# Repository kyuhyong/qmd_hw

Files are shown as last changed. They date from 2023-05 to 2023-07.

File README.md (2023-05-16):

# Q_Motor_Driver_hw

A stackable BLDC motor controller board based and compatible with Odrive project (https://github.com/madcowswe/ODriveHardware).

Part of this project is based from azmat's single channel BLDC controller board (https://github.com/azmat-bilal/bldc_motor_controller_pcb.git)

## Introduction

This project includes 3 PCB boards as Main Board(MB), M0 Board(M0B) and M1 Board(M1B). 

- MB : Main controller, USB, CAN interface

- M0B : Gate driver for M0, 5V power supply for MB
- M1B : Gate driver for M1

MB is in between M0B and M1B which are connected by 2mm pitch socket and header. 

If only 1 axis needed the M1B can be removed. 

If more power is needed, simply redesign M0B or M1B with higher power FET's and put together with MB.

## Odrive compatibility

This project is supposed to be compatible with odrive v3.6-56V.

<div align="center">
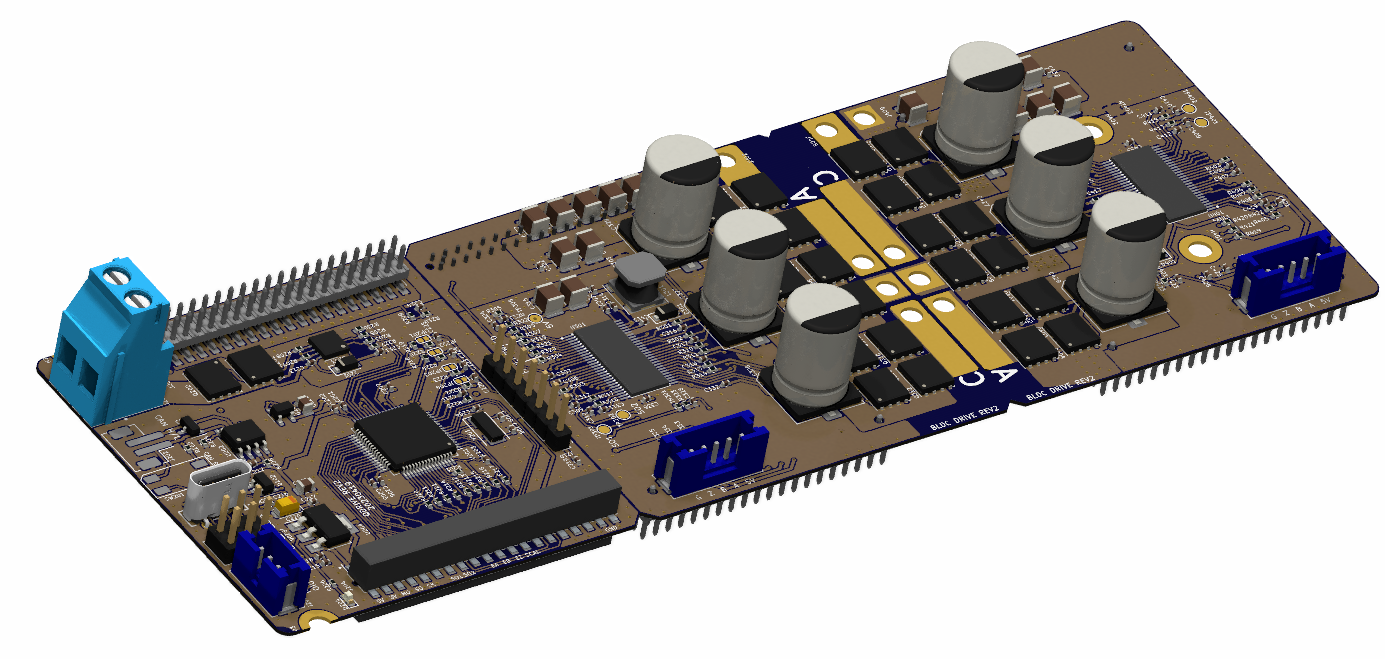
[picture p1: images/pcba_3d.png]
  
</div>

## Announcement

This project is still in development and need modification to be working as expected.

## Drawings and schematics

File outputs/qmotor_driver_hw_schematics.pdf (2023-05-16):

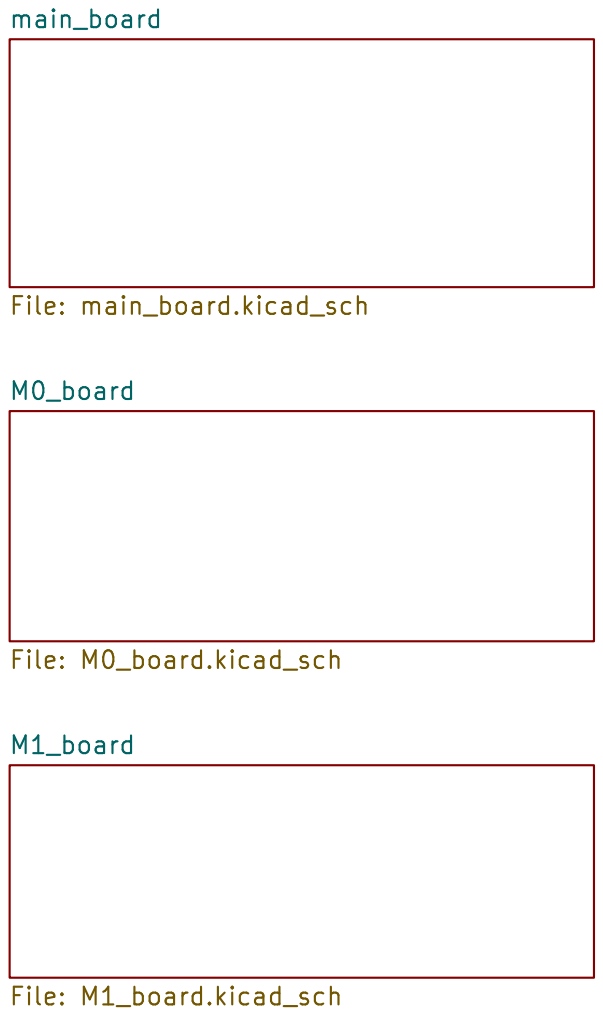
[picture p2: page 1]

Id: 1/4 Title: Q BLDC Motor Driver MB

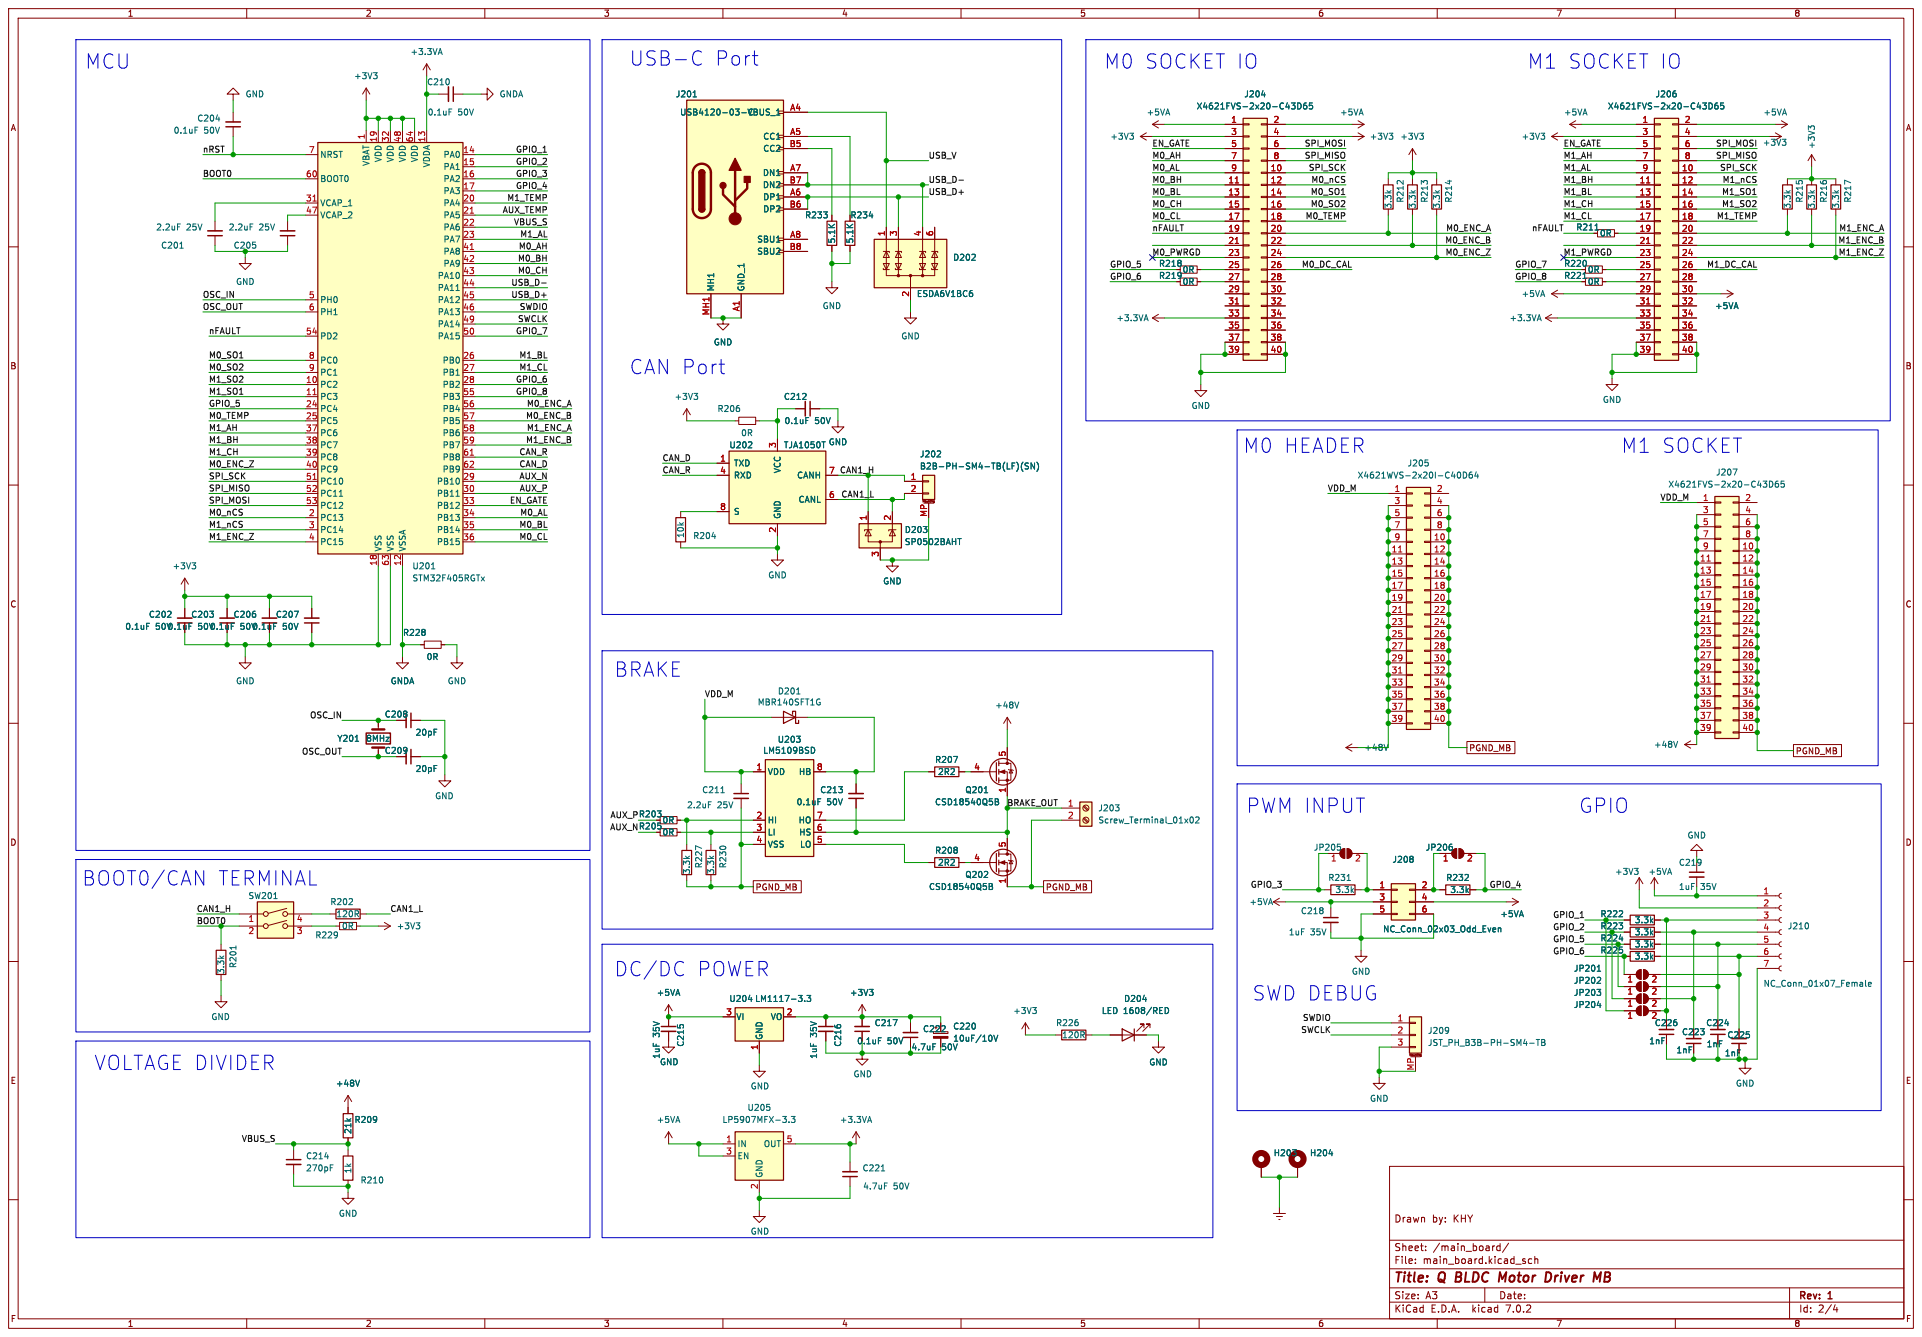
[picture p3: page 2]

1 PC2 10 PC3 11 VSSA 12 VDDA 13 PA0 14 PA1 15 PA2 16 PA3 17 VSS 18 VDD 19 PC13 2 PA4 20 PA5 21 PA6 22 PA7 23 PC4 24 PC5 25 PB0 26 PB1 27 PB2 28 PB10 29 PC14 3 PB11 30 VCAP_1 31 VDD 32 PB12 33 PB13 34 PB14 35 PB15 36 PC6 37 PC7 38 PC8 39 PC15 4 PC9 40 PA8 41 PA9 42 PA10 43 PA11 44 PA12 45 PA13 46 VCAP_2 47 VDD 48 PA14 49 PH0 5 PA15 50 PC10 51 PC11 52 PC12 53 PD2 54 PB3 55 PB4 56 PB5 57 PB6 58 PB7 59 PH1 6 BOOT0 60 PB8 61 PB9 62 VSS 63 VDD 64 NRST 7 PC0 8 PC1 9 U201 STM32F405RGTx +3V3 R228

J202 B2B-PH-SM4-TB(LF)(SN) GND

Id: 2/4 Title: Q BLDC Motor Driver MB

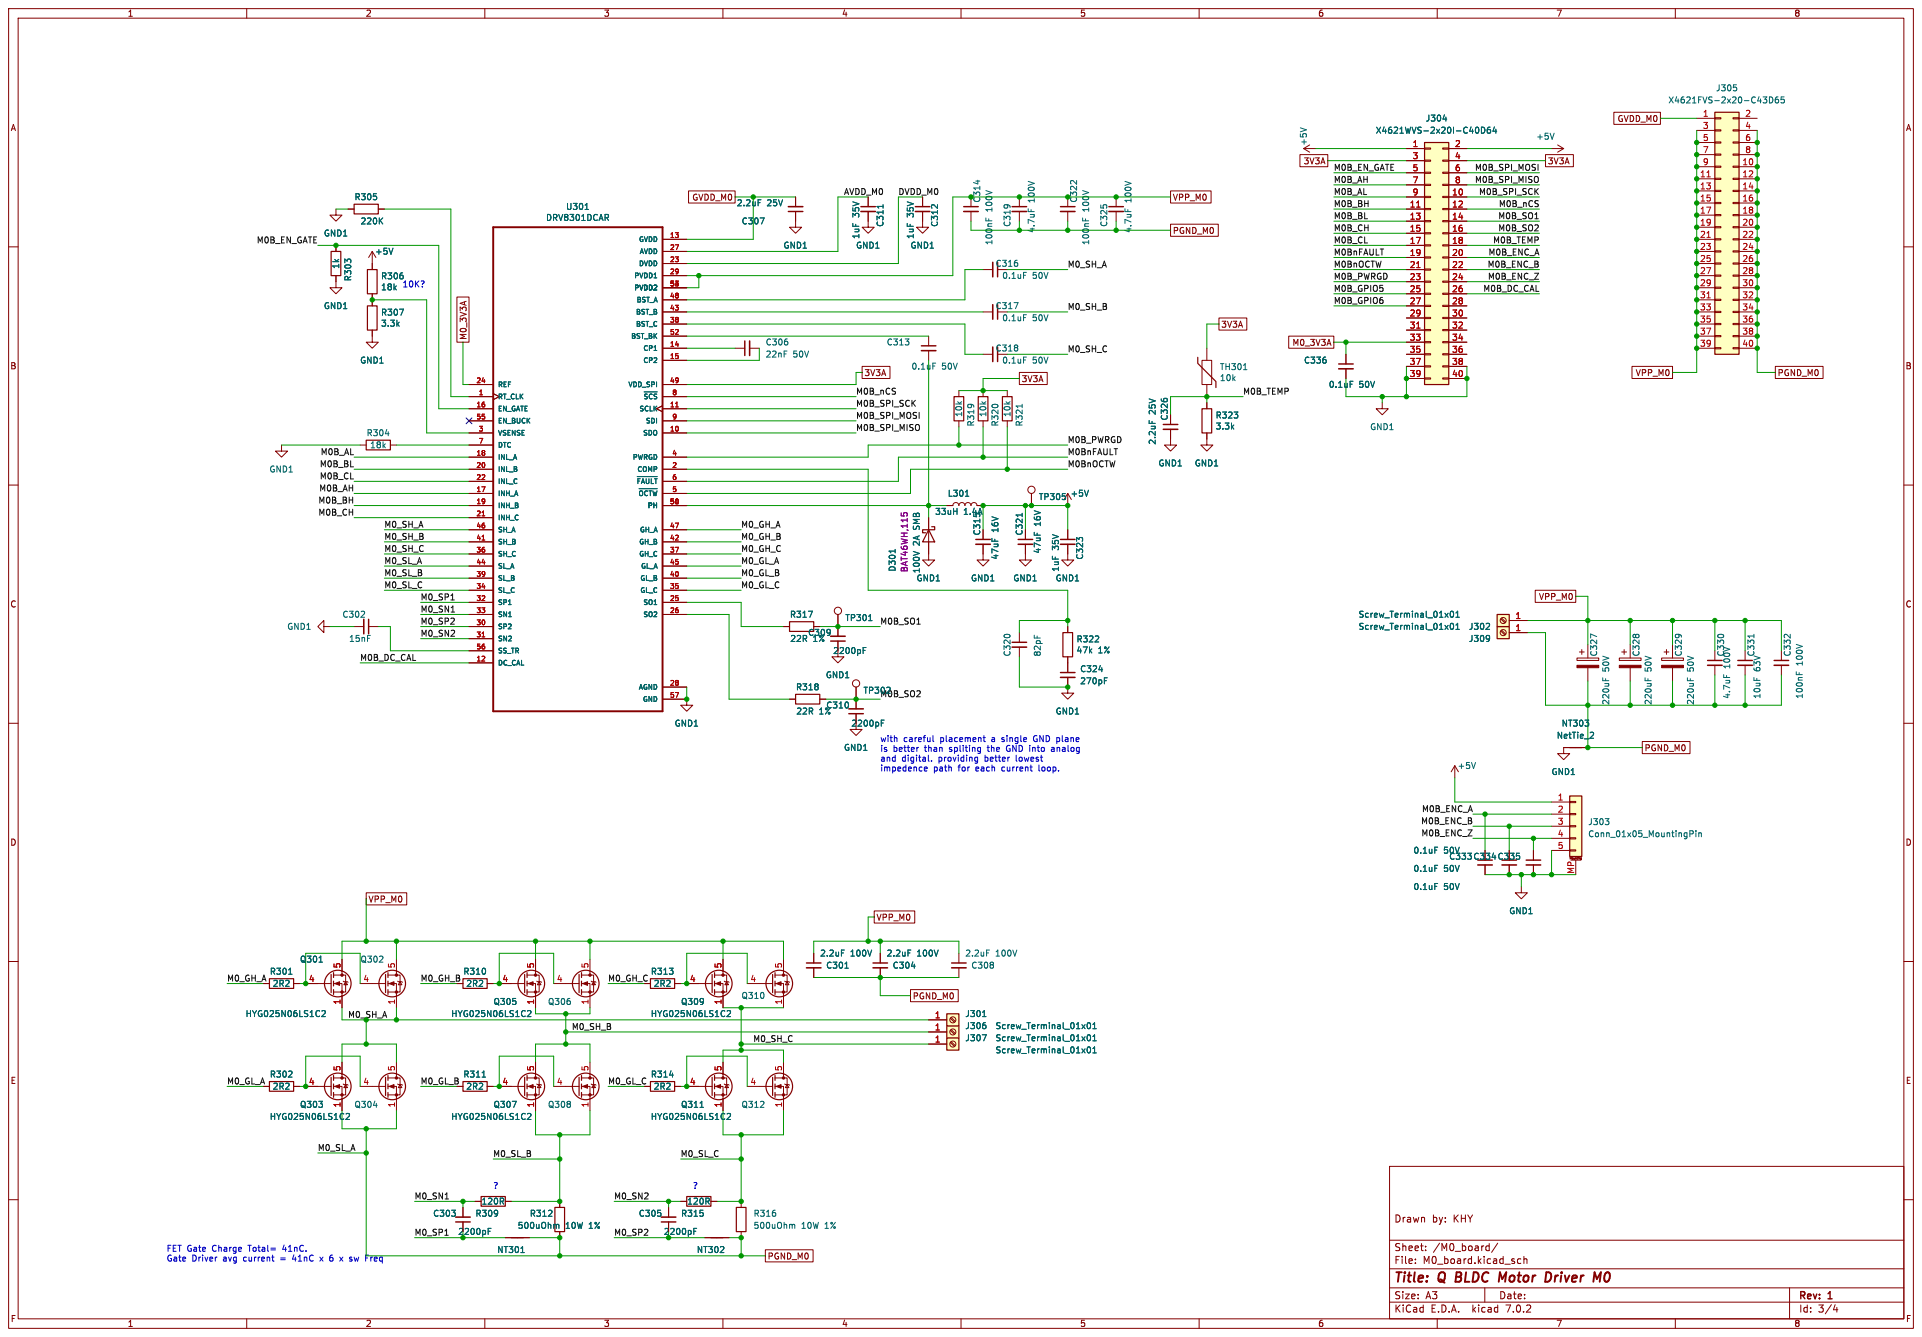
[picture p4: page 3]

FET Gate Charge Total= 41nC. Gate Driver avg current = 41nC x 6 x sw Freq

Id: 3/4 Title: Q BLDC Motor Driver M0

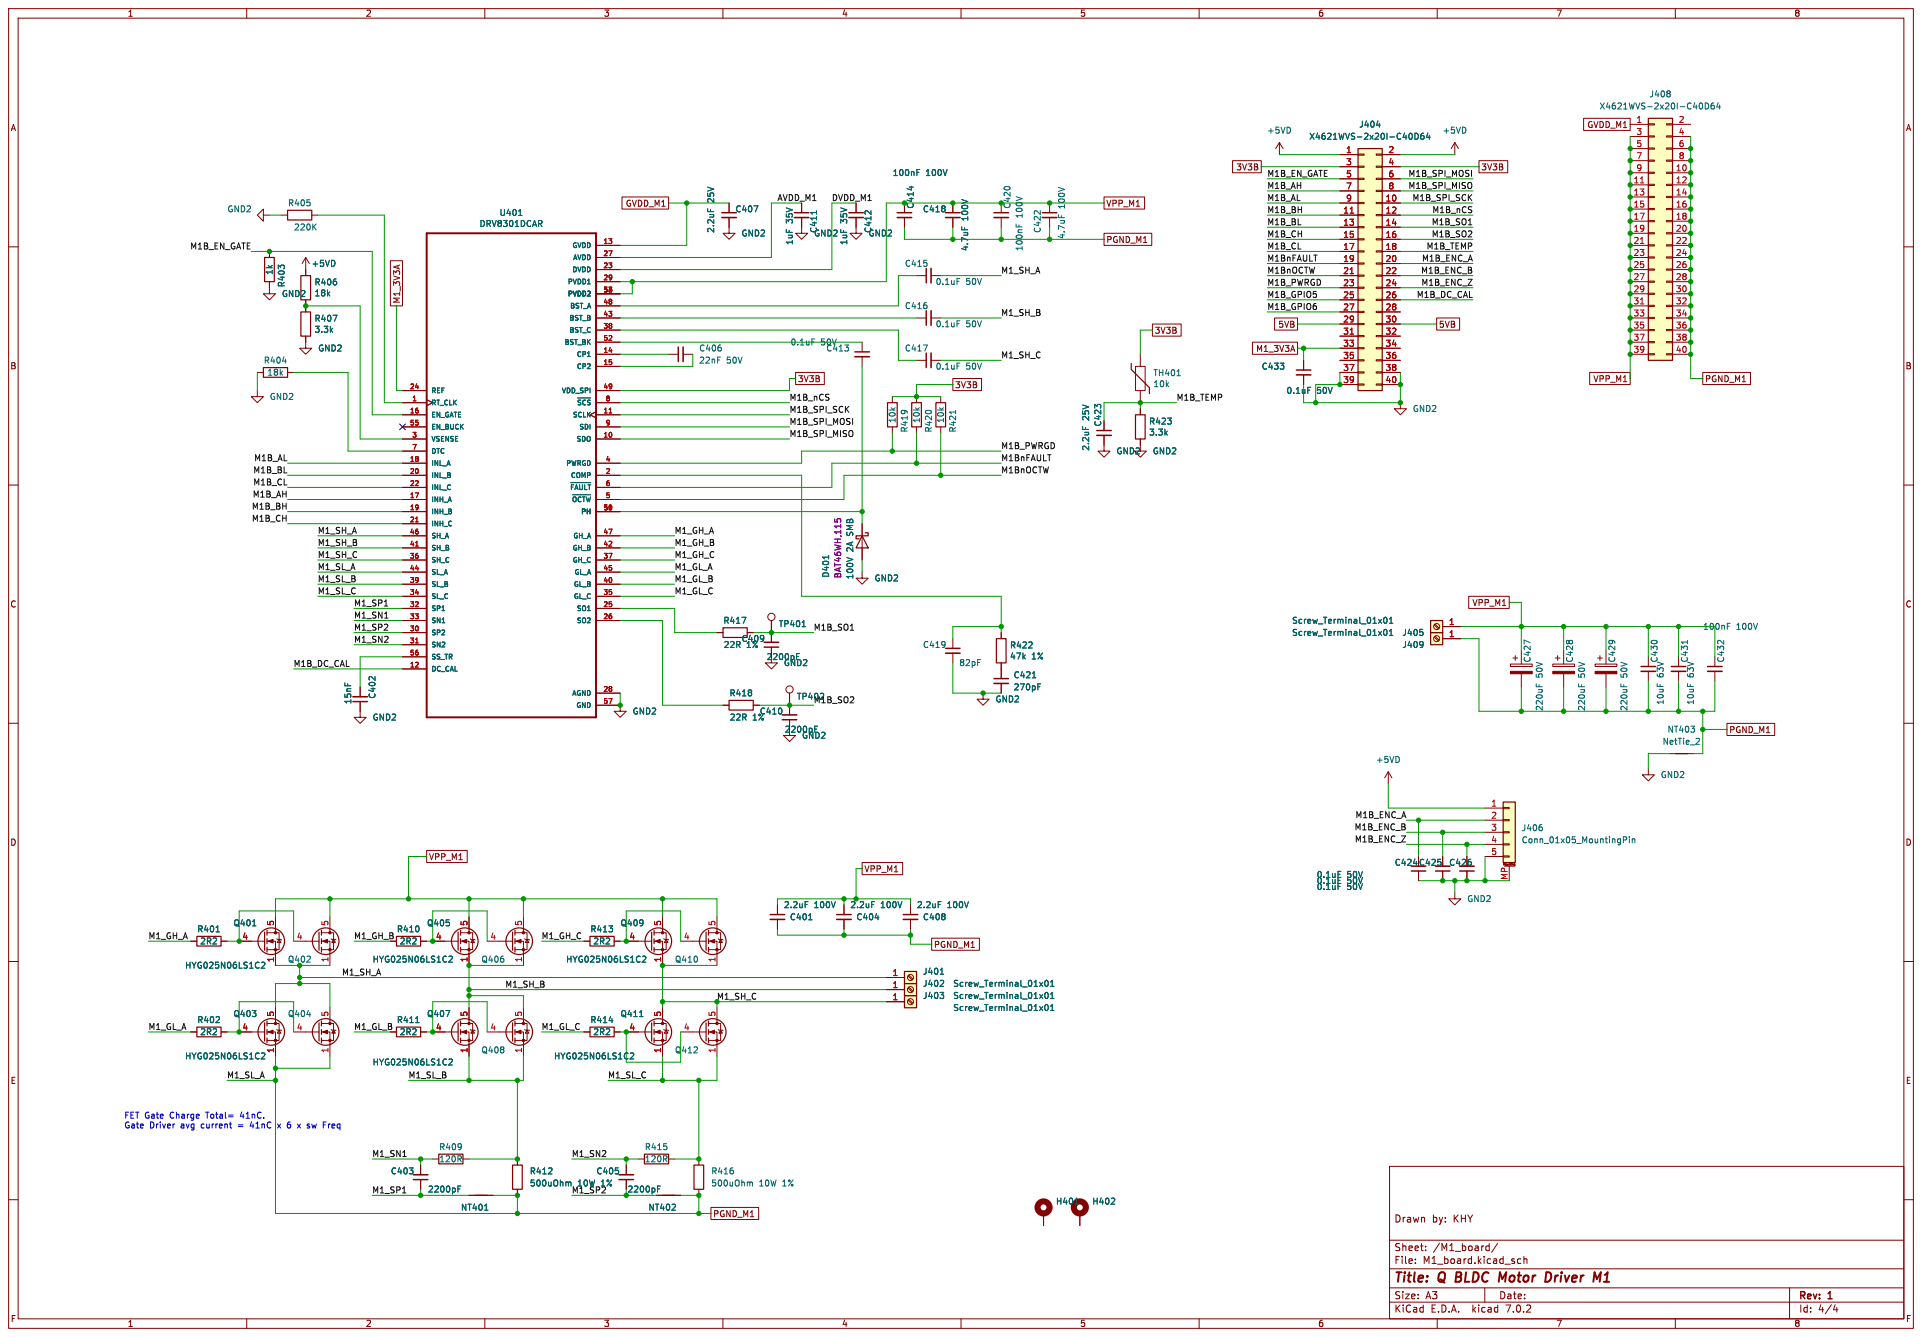
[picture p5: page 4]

Id: 4/4 Title: Q BLDC Motor Driver M1

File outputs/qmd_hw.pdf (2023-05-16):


Id: 1/4 Title: Q Motor Driver MB

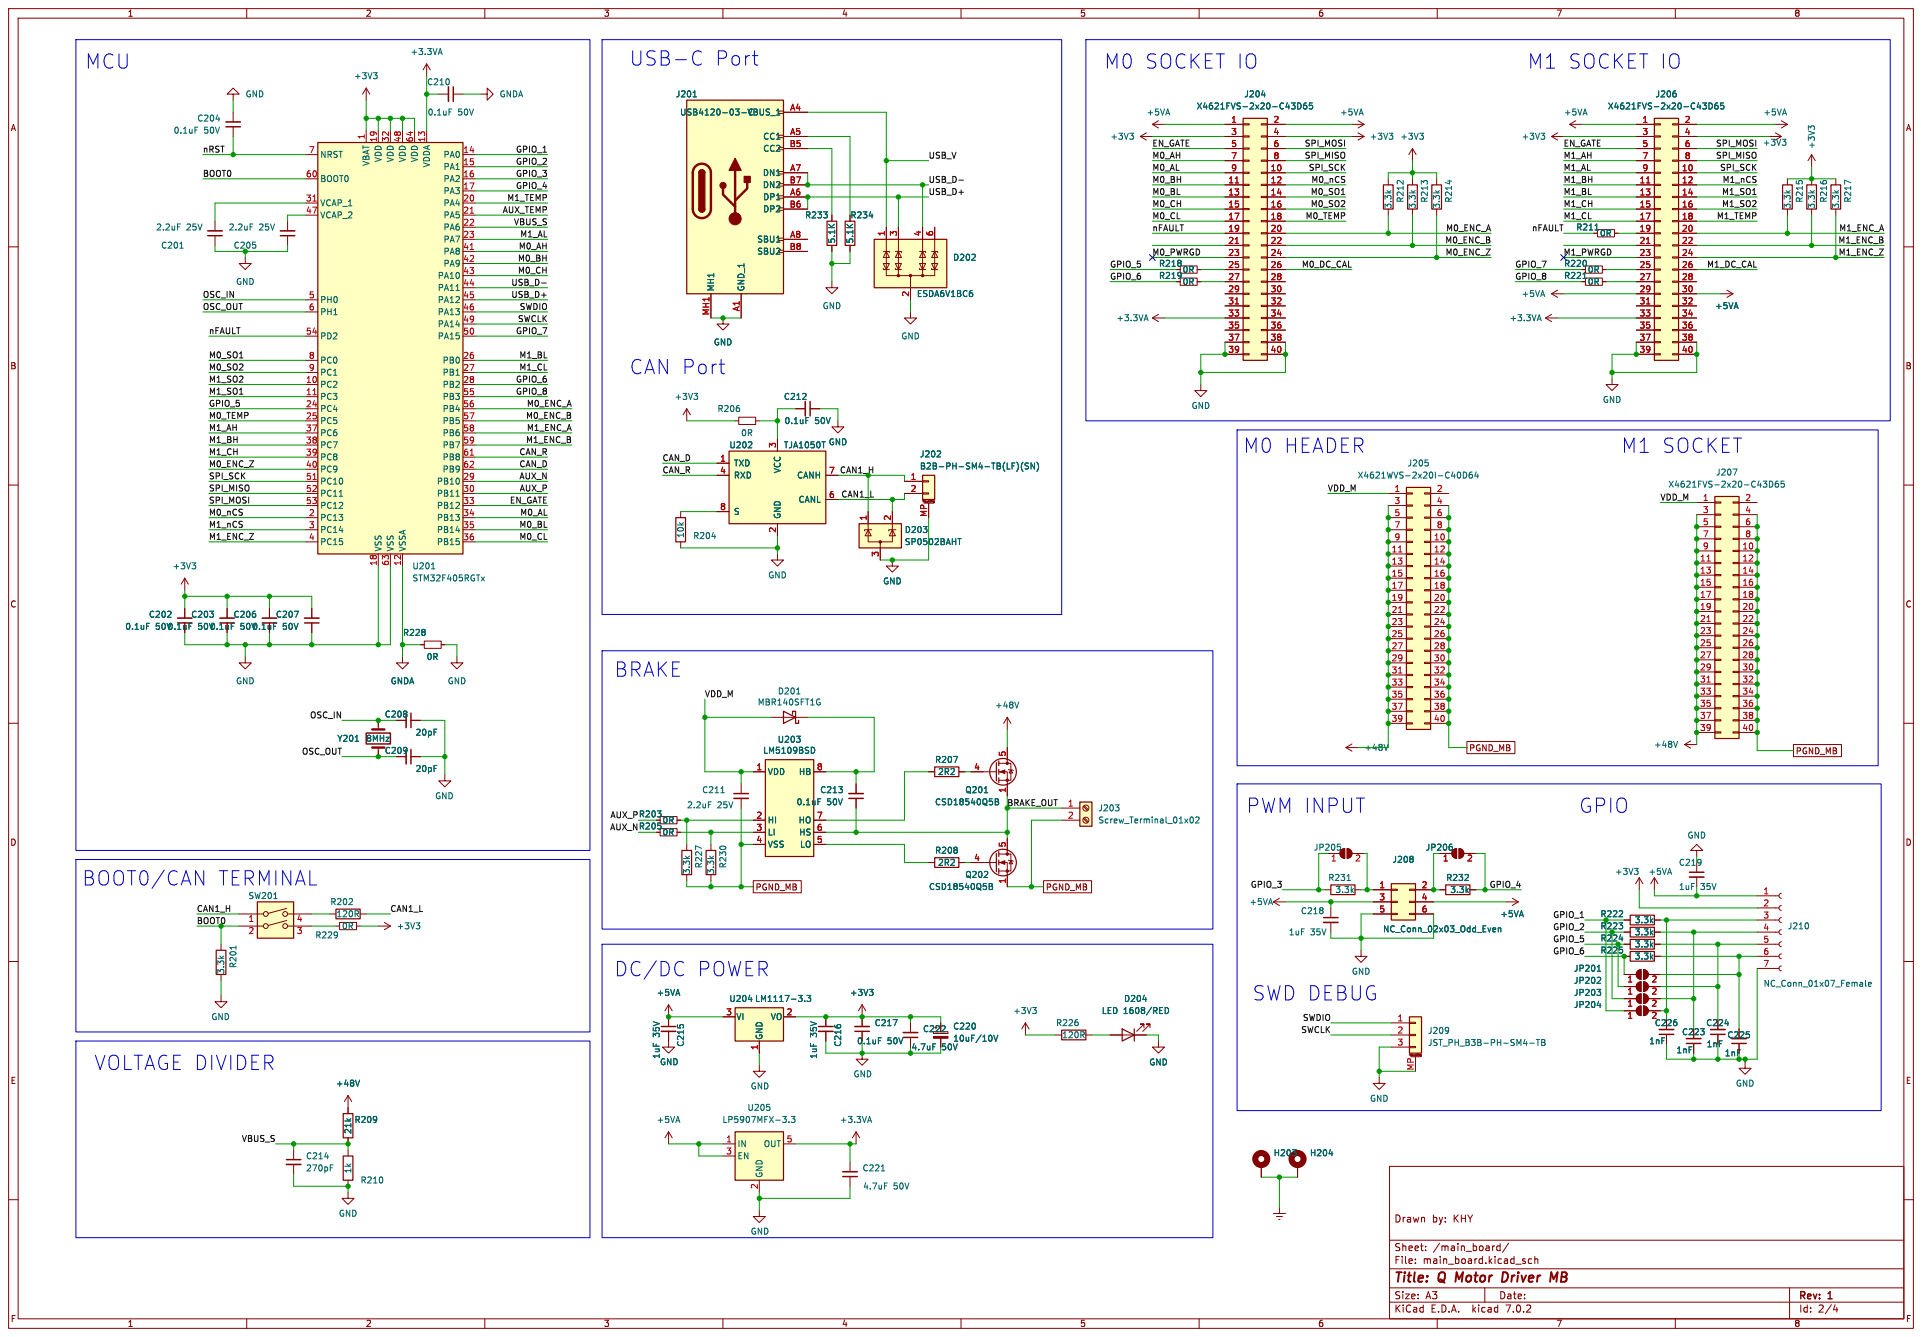
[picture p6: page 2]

1 PC2 10 PC3 11 VSSA 12 VDDA 13 PA0 14 PA1 15 PA2 16 PA3 17 VSS 18 VDD 19 PC13 2 PA4 20 PA5 21 PA6 22 PA7 23 PC4 24 PC5 25 PB0 26 PB1 27 PB2 28 PB10 29 PC14 3 PB11 30 VCAP_1 31 VDD 32 PB12 33 PB13 34 PB14 35 PB15 36 PC6 37 PC7 38 PC8 39 PC15 4 PC9 40 PA8 41 PA9 42 PA10 43 PA11 44 PA12 45 PA13 46 VCAP_2 47 VDD 48 PA14 49 PH0 5 PA15 50 PC10 51 PC11 52 PC12 53 PD2 54 PB3 55 PB4 56 PB5 57 PB6 58 PB7 59 PH1 6 BOOT0 60 PB8 61 PB9 62 VSS 63 VDD 64 NRST 7 PC0 8 PC1 9 U201 STM32F405RGTx GND

J202 B2B-PH-SM4-TB(LF)(SN) GND

Id: 2/4 Title: Q Motor Driver MB

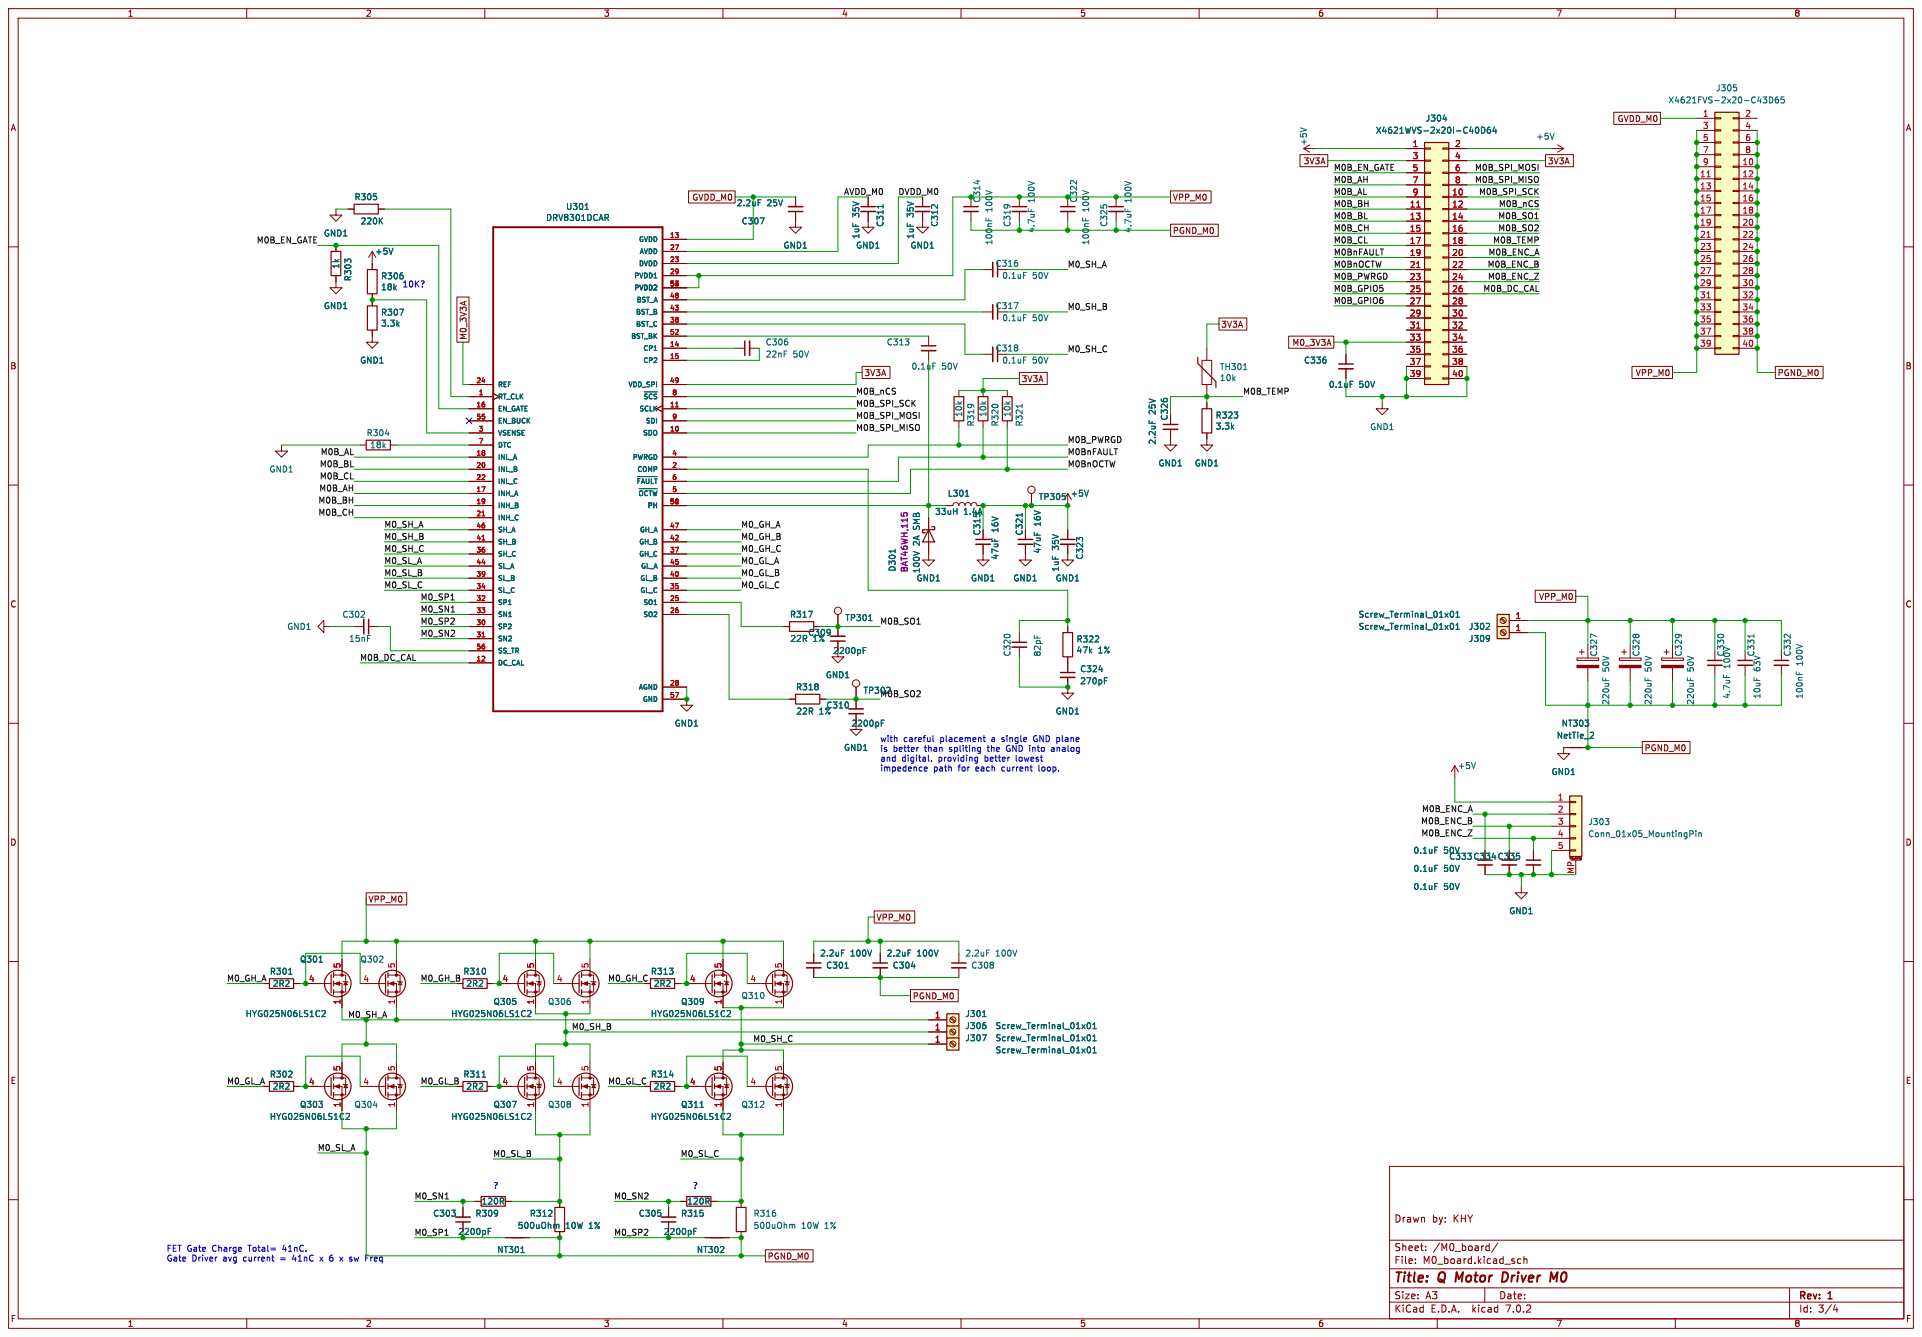
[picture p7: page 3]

FET Gate Charge Total= 41nC. Gate Driver avg current = 41nC x 6 x sw Freq

Id: 3/4 Title: Q Motor Driver M0

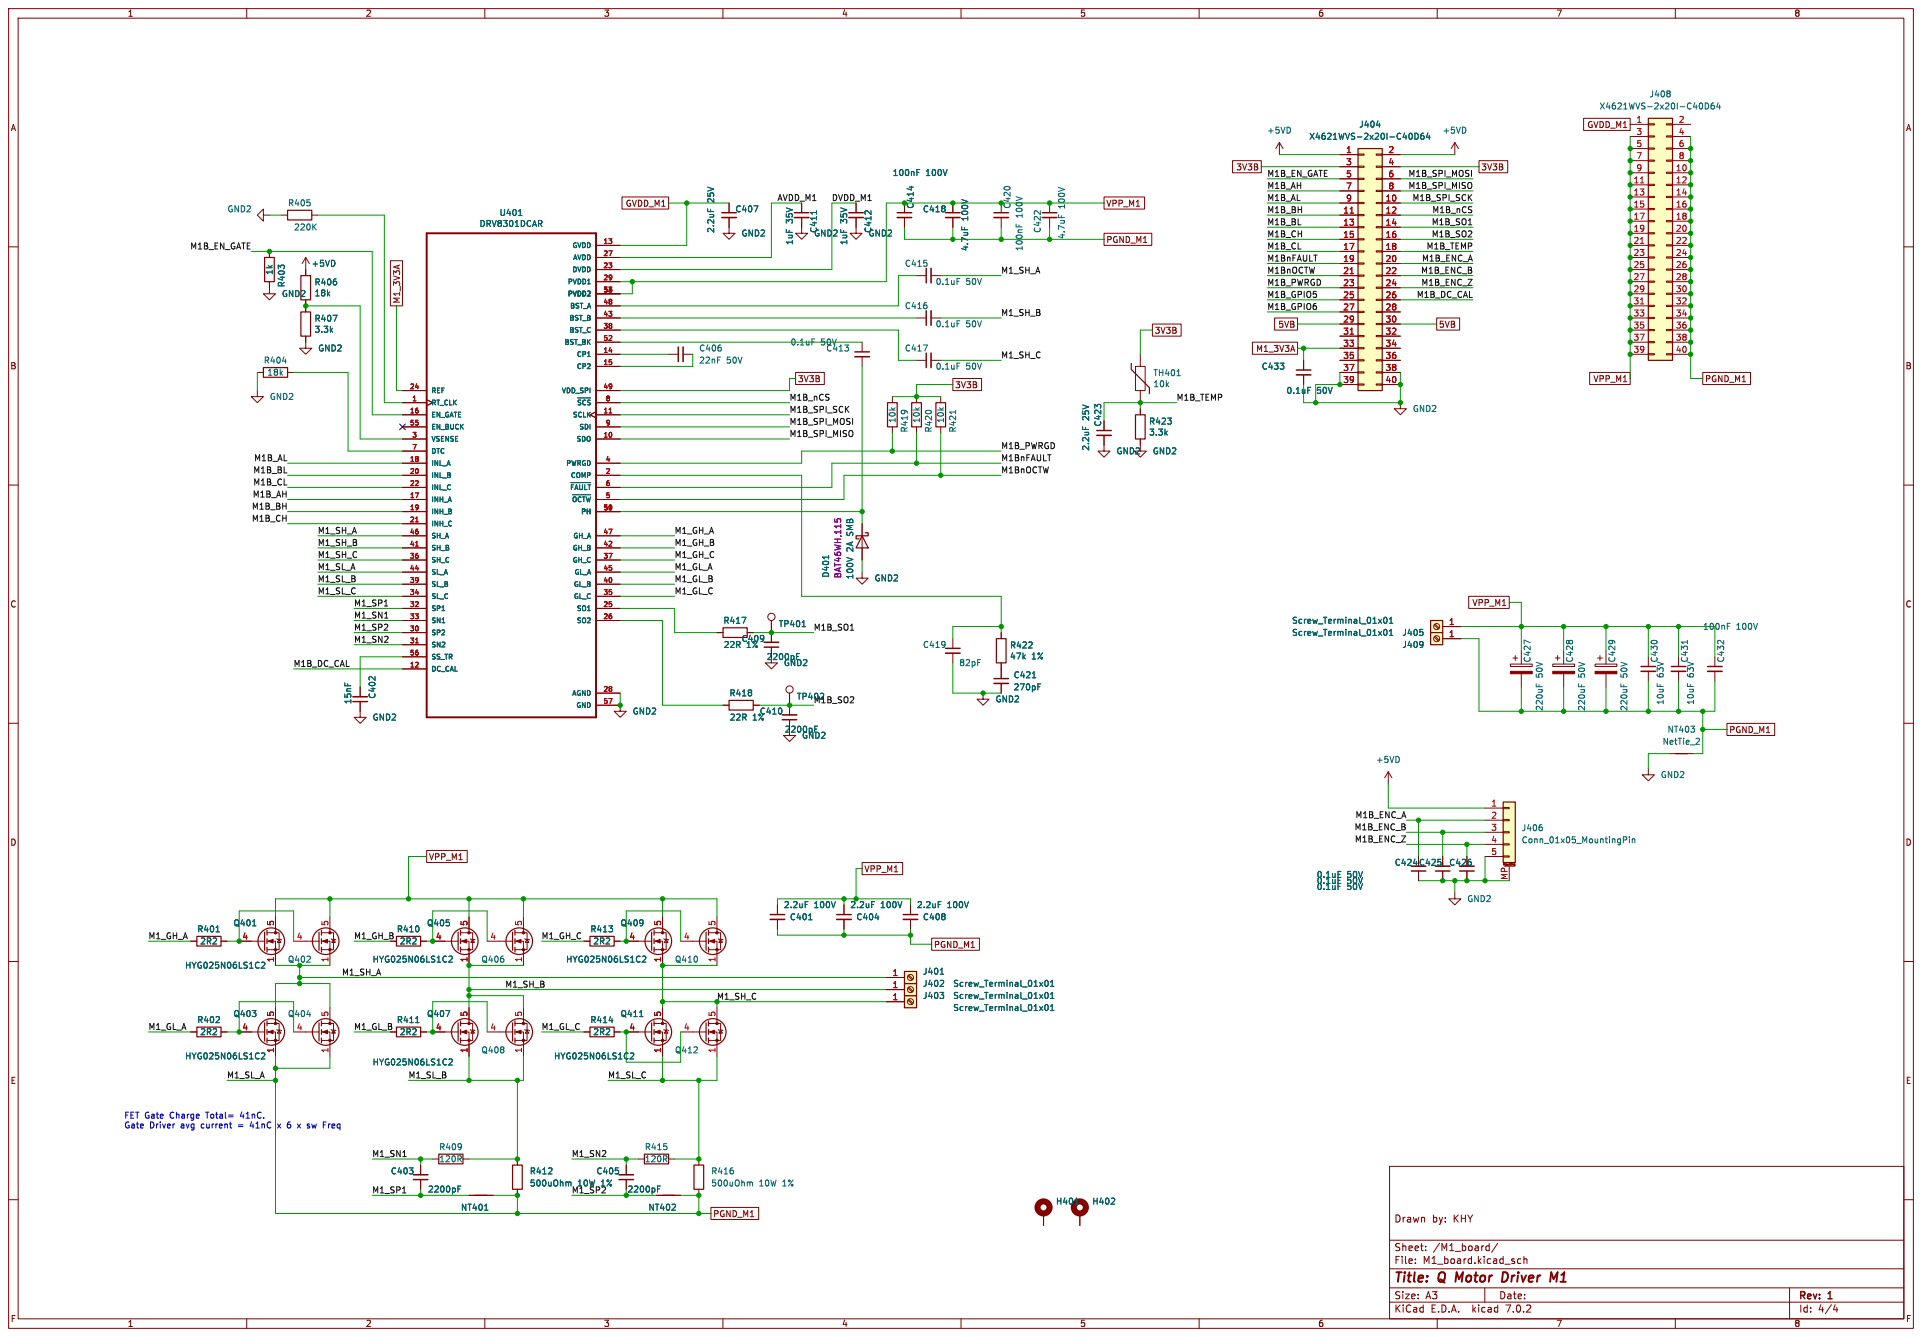
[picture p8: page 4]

Id: 4/4 Title: Q Motor Driver M1

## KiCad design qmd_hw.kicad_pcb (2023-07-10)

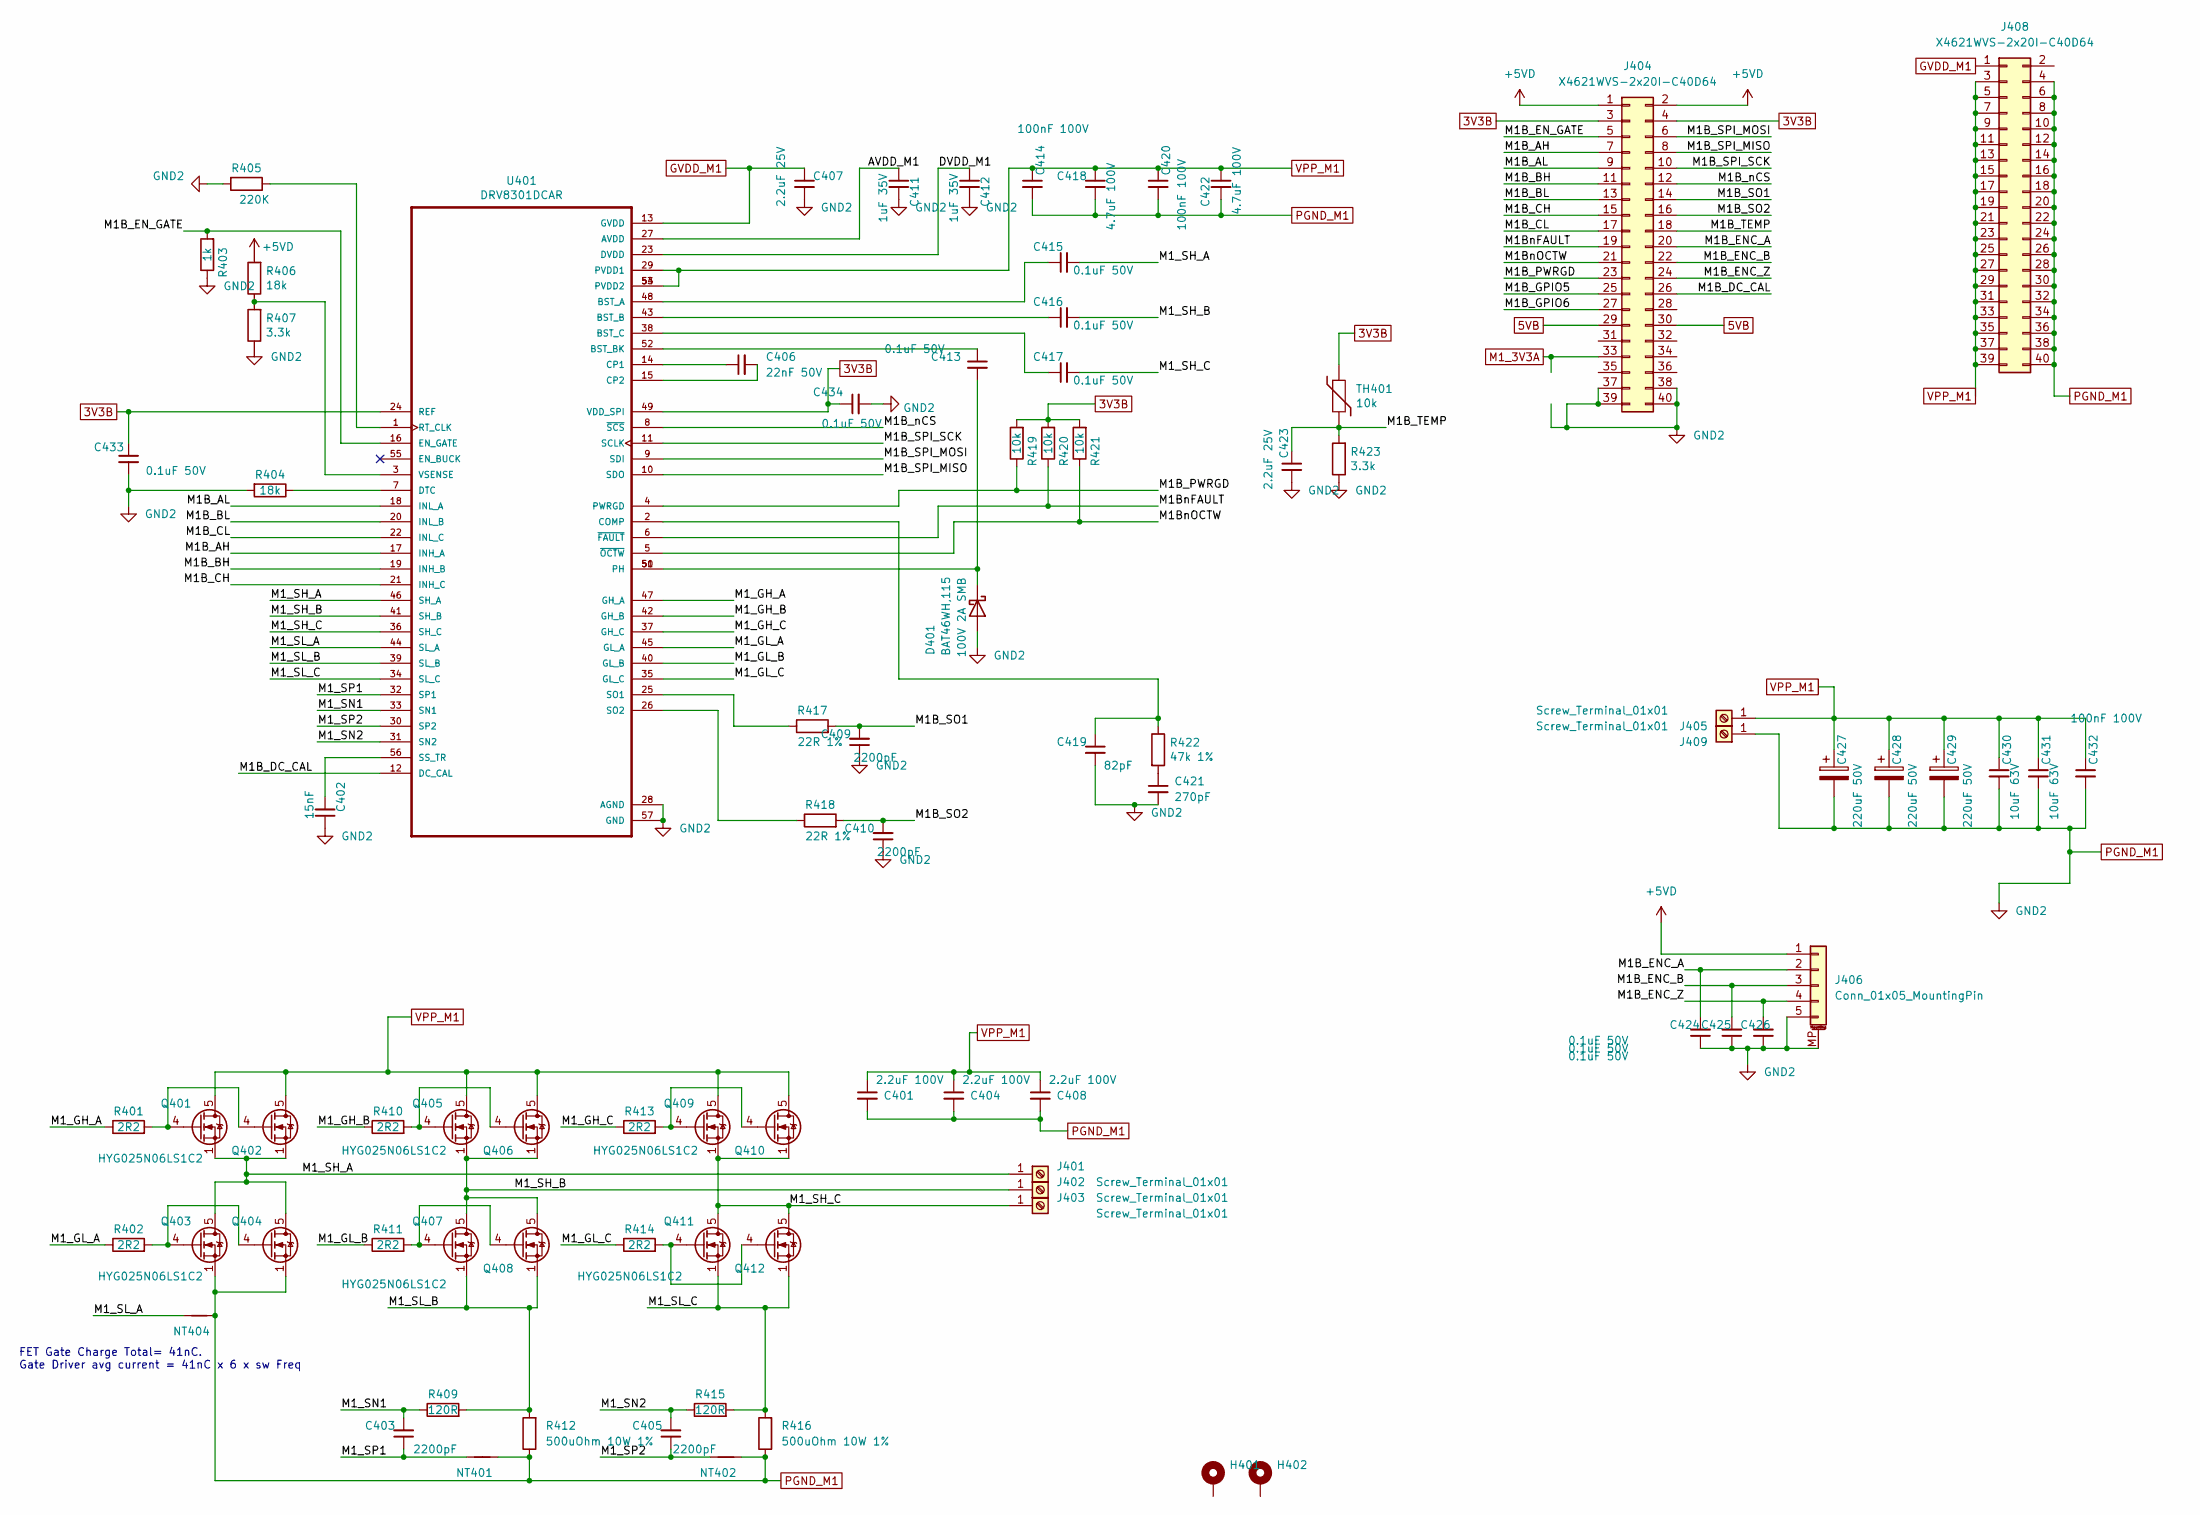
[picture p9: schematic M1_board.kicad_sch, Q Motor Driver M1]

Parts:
C401, C404, C408: 2.2uF 100V; C_1210_3225Metric; MPN HMK325B7225KN-T; JLCPN C92775
C402: 15nF; C_0402_1005Metric; MPN GCM155R71E153JA55D
C403, C405, C409, C410: 2200pF; C_0402_1005Metric; MPN CL05B222KB5NNNC; JLCPN C84703
C406: 22nF 50V; C_0402_1005Metric; MPN CL05B223KB5VPNC; JLCPN C307335
C407, C423: 2.2uF 25V; C_0603_1608Metric; MPN CL10A225KB8NNNC; JLCPN C913904
C411, C412: 1uF 35V; C_0603_1608Metric; MPN CL05A105KL5NRNC; JLCPN C307413
C413, C415, C416, C417, C434: 0.1uF 50V; C_0402_1005Metric
C414, C420, C432: 100nF 100V; C_0402_1005Metric; MPN GRM155R62A104KE14D; JLCPN C162178
C418: 4.7uF 100V; C_1210_3225Metric; MPN HMK325C7475KMHPE; JLCPN C385986
C419: 82pF; C_0402_1005Metric; MPN C1005NP0820JGTS; JLCPN C147470
C421: 270pF; C_0603_1608Metric; MPN CGA2B2C0G1H271JT0Y0F; JLCPN C695156
C422: 4.7uF 100V; C_1210_3225Metric; MPN HMK325C7475KN-TE
C424, C425, C426, C433: 0.1uF 50V; C_0603_1608Metric; MPN CL10B104KB8NNNC; JLCPN C1591
C427, C428, C429: 220uF 50V; CP_Elec_10x14.3; MPN EEHZS1H221P; JLCPN C385885
C430, C431: 10uF 63V; C_1210_3225Metric; MPN CL32B106KMVNNWE
D401: 100V 2A SMB; D_SOD-123F; MPN BAT46WH,115; JLCPN C426768
H401: MountingHole_Pad; MountingHole_3.2mm_M3_ISO7380_Pad
H402: MountingHole_Pad; MountingHole_3.2mm_M3_ISO7380_Pad_TopBottom
J401, J402, J403, J405, J409: Screw_Terminal_01x01; SolderWire-2.5sqmm_1x01_D2.4mm_OD3.6mm
J404, J408: X4621WVS-2x20I-C40D64; PinHeader_2x20_P2.0mm_Vertical_SMD_877594051; MPN X4621WVS-2x20I-C40D64; JLCPN C2883178
J406: Conn_01x05_MountingPin; JST_PH_B5B-PH-SM4-TB_1x05-1MP_P2.00mm_Vertical; MPN B5B-PH-SM4-TB(LF)(SN); JLCPN C265085
NT401, NT402, NT404: Net-Tie_2; NetTie-2_SMD_Pad0.5mm
Q401, Q402, Q403, Q404, Q405, Q406, Q407, Q408, Q409, Q410, Q411, Q412: HYG025N06LS1C2; TDSON-8-1; MPN HYG025N06LS1C2
R401, R402, R410, R411, R413, R414: 2R2; R_0603_1608Metric; MPN RC0603FR-072R2L; JLCPN C98220
R403: 1k; R_0402_1005Metric; MPN ERJ-2RKF1001X
R404, R406: 18k; R_0402_1005Metric; MPN CRCW040218K0FKED
R405: 220K; R_0402_1005Metric; MPN CR0402-JW-224GLF; JLCPN C203142
R407, R423: 3.3k; R_0603_1608Metric; MPN RC0603JR-073K3L; JLCPN C114432
R409, R415: 120R; R_0603_1608Metric; MPN ERJ-2RKF1200X
R412, R416: 500uOhm 10W 1%; WSLP3921L5000FEA; MPN WSLP3921L5000FEA
R417, R418: 22R 1%; R_0402_1005Metric; MPN AC0402JR-0722RL; JLCPN C144722
R419, R420, R421: 10k; R_0603_1608Metric; MPN RC0603FR-0710KL
R422: 47k 1%; R_0402_1005Metric; MPN RC0402FR-0747KL; JLCPN C93943
TH401: 10k; R_0402_1005Metric; MPN CRCW040210K0FKEDC
U401: DRV8301DCAR; SOP50P810X120-57N; MPN DRV8301DCAR

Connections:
3V3B: C433.1, C434.1, J404.3, J404.4, R419.2, R420.2, R421.2, TH401.1, U401.24 (REF), U401.49 (VDD_SPI)
5VB: J404.29, J404.30
+5VD: J404.1, J404.2, J406.1, R406.2
/M1_board/AVDD_M1: C411.1, U401.27 (AVDD)
/M1_board/DVDD_M1: C412.1, U401.23 (DVDD)
/M1_board/M1B_AH: J404.7, U401.17 (INH_A)
/M1_board/M1B_AL: J404.9, U401.18 (INL_A)
/M1_board/M1B_BH: J404.11, U401.19 (INH_B)
/M1_board/M1B_BL: J404.13, U401.20 (INL_B)
/M1_board/M1B_CH: J404.15, U401.21 (INH_C)
/M1_board/M1B_CL: J404.17, U401.22 (INL_C)
/M1_board/M1B_DC_CAL: J404.26, U401.12 (DC_CAL)
/M1_board/M1B_ENC_A: C424.2, J404.20, J406.2
/M1_board/M1B_ENC_B: C425.2, J404.22, J406.3
/M1_board/M1B_ENC_Z: C426.2, J404.24, J406.4
/M1_board/M1B_EN_GATE: J404.5, R403.2, U401.16 (EN_GATE)
/M1_board/M1B_GPIO5: J404.25
/M1_board/M1B_GPIO6: J404.27
/M1_board/M1B_PWRGD: J404.23, R419.1, U401.4 (PWRGD)
/M1_board/M1B_SO1: C409.2, J404.14, R417.2
/M1_board/M1B_SO2: C410.2, J404.16, R418.2
/M1_board/M1B_SPI_MISO: J404.8, U401.10 (SDO)
/M1_board/M1B_SPI_MOSI: J404.6, U401.9 (SDI)
/M1_board/M1B_SPI_SCK: J404.10, U401.11 (SCLK)
/M1_board/M1B_TEMP: C423.1, J404.18, R423.2, TH401.2
/M1_board/M1B_nCS: J404.12, U401.8 (~SCS)
/M1_board/M1BnFAULT: J404.19, R420.1, U401.6 (~FAULT)
/M1_board/M1BnOCTW: J404.21, R421.1, U401.5 (~OCTW)
/M1_board/M1_GH_A: R401.1, U401.47 (GH_A)
/M1_board/M1_GH_B: R410.1, U401.42 (GH_B)
/M1_board/M1_GH_C: R413.1, U401.37 (GH_C)
/M1_board/M1_GL_A: R402.1, U401.45 (GL_A)
/M1_board/M1_GL_B: R411.1, U401.40 (GL_B)
/M1_board/M1_GL_C: R414.1, U401.35 (GL_C)
/M1_board/M1_SH_A: C415.2, J401.1, Q401.1 (S), Q401.2 (S), Q401.3 (S), Q402.1 (S), Q402.2 (S), Q402.3 (S), Q403.5 (D), Q404.5 (D), U401.46 (SH_A)
/M1_board/M1_SH_B: C416.2, J402.1, Q405.1 (S), Q405.2 (S), Q405.3 (S), Q406.1 (S), Q406.2 (S), Q406.3 (S), Q407.5 (D), Q408.5 (D), U401.41 (SH_B)
/M1_board/M1_SH_C: C417.2, J403.1, Q409.1 (S), Q409.2 (S), Q409.3 (S), Q410.1 (S), Q410.2 (S), Q410.3 (S), Q411.5 (D), Q412.5 (D), U401.36 (SH_C)
/M1_board/M1_SL_A: NT404.1, U401.44 (SL_A)
/M1_board/M1_SL_B: Q407.1 (S), Q407.2 (S), Q407.3 (S), Q408.1 (S), Q408.2 (S), Q408.3 (S), R409.2, R412.2, U401.39 (SL_B)
/M1_board/M1_SL_C: Q411.1 (S), Q411.2 (S), Q411.3 (S), Q412.1 (S), Q412.2 (S), Q412.3 (S), R415.2, R416.2, U401.34 (SL_C)
/M1_board/M1_SN1: C403.2, R409.1, U401.33 (SN1)
/M1_board/M1_SN2: C405.2, R415.1, U401.31 (SN2)
/M1_board/M1_SP1: C403.1, NT401.1, U401.32 (SP1)
/M1_board/M1_SP2: C405.1, NT402.1, U401.30 (SP2)
GVDD_M1: C407.1, J408.1, U401.13 (GVDD)
M1_3V3A: J404.33
unnamed: C421.1, R422.2
unnamed: C413.2, D401.1 (K), U401.50 (PH), U401.51 (PH)
unnamed: Q401.4 (G), Q402.4 (G), R401.2
unnamed: Q403.4 (G), Q404.4 (G), R402.2
unnamed: Q405.4 (G), Q406.4 (G), R410.2
unnamed: Q407.4 (G), Q408.4 (G), R411.2
unnamed: Q409.4 (G), Q410.4 (G), R413.2
unnamed: Q411.4 (G), Q412.4 (G), R414.2
unnamed: C415.1, U401.48 (BST_A)
unnamed: C416.1, U401.43 (BST_B)
unnamed: C413.1, U401.52 (BST_BK)
unnamed: C417.1, U401.38 (BST_C)
unnamed: C419.1, R422.1, U401.2 (COMP)
unnamed: C406.1, U401.14 (CP1)
unnamed: C406.2, U401.15 (CP2)
unnamed: R404.1, U401.7 (DTC)
unnamed: R405.1, U401.1 (RT_CLK)
unnamed: R417.1, U401.25 (SO1)
unnamed: R418.1, U401.26 (SO2)
unnamed: C402.2, U401.56 (SS_TR)
unnamed: R406.1, R407.2, U401.3 (VSENSE)
PGND_M1: C401.2, C402.1, C404.2, C407.2, C408.2, C409.1, C410.1, C411.2, C412.2, C414.2, C418.2, C419.2, C420.2, C421.2, C422.2, C423.2, C424.1, C425.1, C426.1, C427.2, C428.2, C429.2, C430.2, C431.2, C432.2, C433.2, C434.2, D401.2 (A), J404.37, J404.38, J404.39, J404.40, J406.5, J406.MP (MountPin), J408.4, J408.6, J408.8, J408.10, J408.12, J408.14, J408.16, J408.18, J408.20, J408.22, J408.24, J408.26, J408.28, J408.30, J408.32, J408.34, J408.36, J408.38, J408.40, J409.1, NT401.2, NT402.2, NT404.2, Q403.1 (S), Q403.2 (S), Q403.3 (S), Q404.1 (S), Q404.2 (S), Q404.3 (S), R403.1, R404.2, R405.2, R407.1, R412.1, R416.1, R423.1, U401.28 (AGND), U401.57 (GND)
VPP_M1: C401.1, C404.1, C408.1, C414.1, C418.1, C420.1, C422.1, C427.1, C428.1, C429.1, C430.1, C431.1, C432.1, J405.1, J408.3, J408.5, J408.7, J408.9, J408.11, J408.13, J408.15, J408.17, J408.19, J408.21, J408.23, J408.25, J408.27, J408.29, J408.31, J408.33, J408.35, J408.37, J408.39, Q401.5 (D), Q402.5 (D), Q405.5 (D), Q406.5 (D), Q409.5 (D), Q410.5 (D), U401.29 (PVDD1), U401.53 (PVDD2), U401.54 (PVDD2)

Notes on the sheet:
FET Gate Charge Total= 41nC. Gate Driver avg current = 41nC x 6 x sw Freq

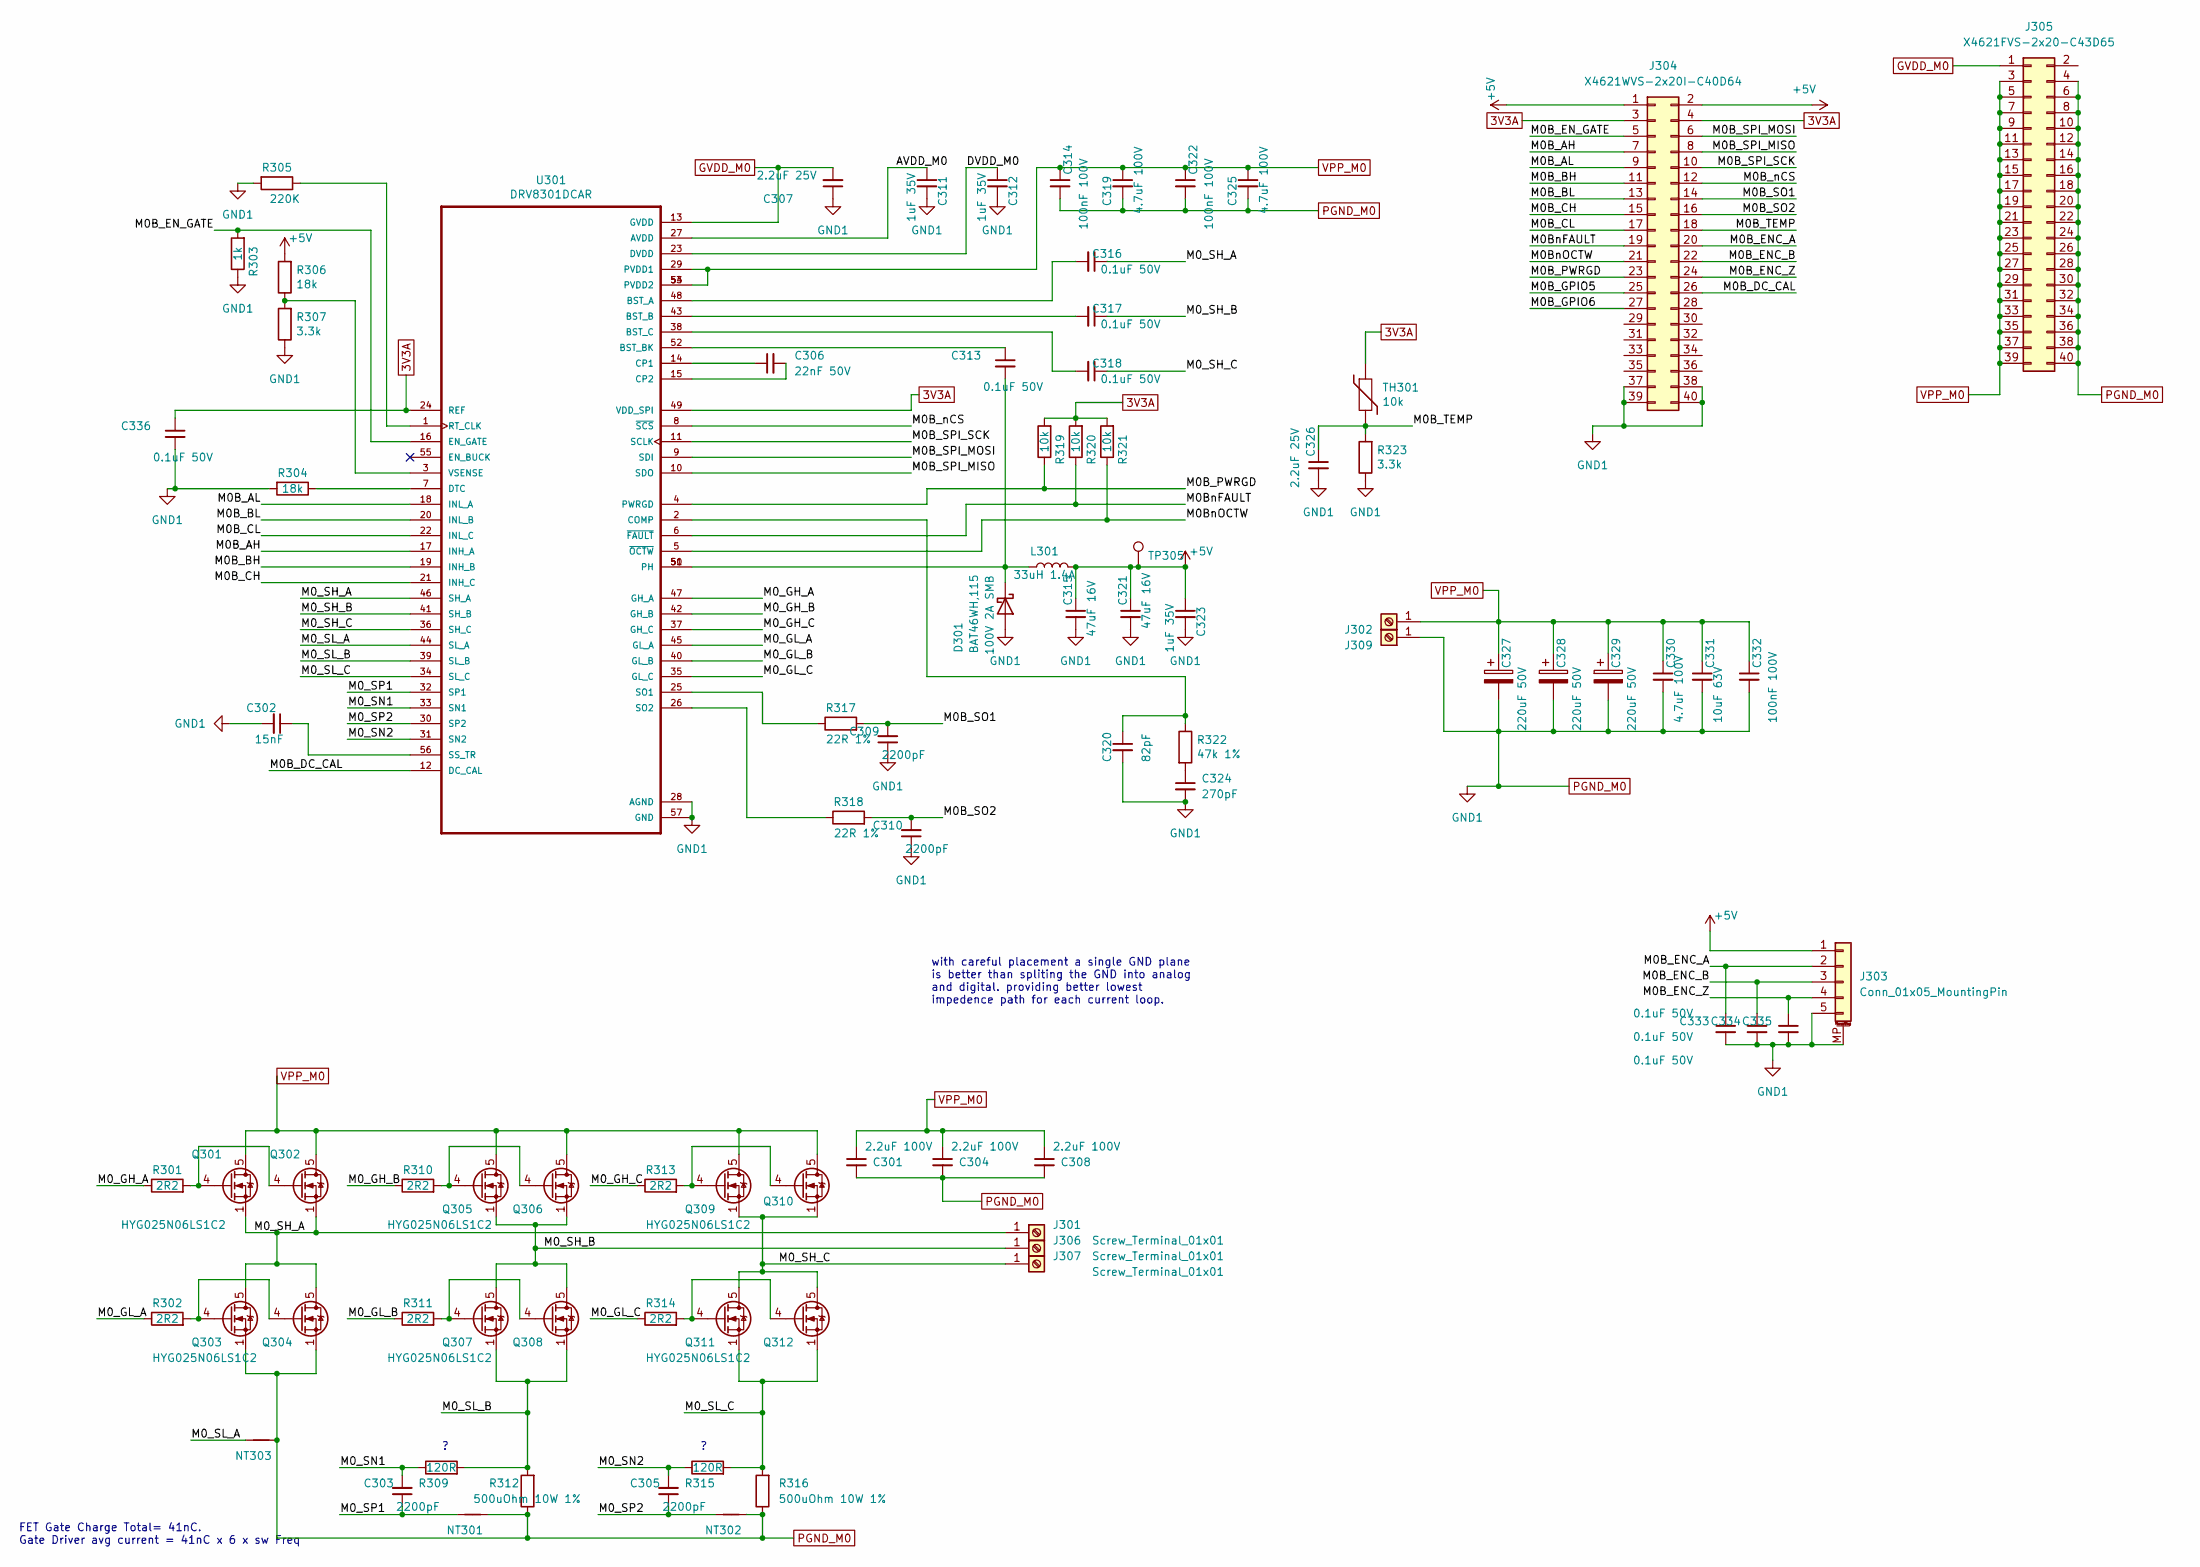
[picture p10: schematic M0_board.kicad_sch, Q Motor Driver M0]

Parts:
C301, C304, C308: 2.2uF 100V; C_1210_3225Metric; MPN HMK325B7225KN-T; JLCPN C92775
C302: 15nF; C_0402_1005Metric; MPN GCM155R71E153JA55D
C303, C305, C309, C310: 2200pF; C_0402_1005Metric; MPN CL05B222KB5NNNC; JLCPN C84703
C306: 22nF 50V; C_0402_1005Metric; MPN CL05B223KB5VPNC; JLCPN C307335
C307, C326: 2.2uF 25V; C_0603_1608Metric; MPN CL10A225KB8NNNC; JLCPN C913904
C311, C312, C323: 1uF 35V; C_0603_1608Metric; MPN CL05A105KL5NRNC; JLCPN C307413
C313, C316, C317, C318, C336: 0.1uF 50V; C_0402_1005Metric
C314, C322, C332: 100nF 100V; C_0402_1005Metric; MPN GRM155R62A104KE14D; JLCPN C162178
C315, C321: 47uF 16V; C_1210_3225Metric; MPN GRM32EC81C476KE15L
C319, C325: 4.7uF 100V; C_1210_3225Metric; MPN HMK325C7475KN-TE
C320: 82pF; C_0402_1005Metric; MPN C1005NP0820JGTS; JLCPN C147470
C324: 270pF; C_0603_1608Metric; MPN CGA2B2C0G1H271JT0Y0F; JLCPN C695156
C327, C328, C329: 220uF 50V; CP_Elec_10x14.3; MPN EEHZS1H221P; JLCPN C385885
C330: 4.7uF 100V; C_1210_3225Metric; MPN HMK325C7475KMHPE; JLCPN C385986
C331: 10uF 63V; C_1210_3225Metric; MPN CL32B106KMVNNWE
C333, C334, C335: 0.1uF 50V; C_0603_1608Metric; MPN CL10B104KB8NNNC; JLCPN C1591
D301: 100V 2A SMB; D_SOD-123F; MPN BAT46WH,115; JLCPN C426768
J301, J302, J306, J307, J309: Screw_Terminal_01x01; SolderWire-2.5sqmm_1x01_D2.4mm_OD3.6mm
J303: Conn_01x05_MountingPin; JST_PH_B5B-PH-SM4-TB_1x05-1MP_P2.00mm_Vertical; MPN B5B-PH-SM4-TB(LF)(SN); JLCPN C265085
J304: X4621WVS-2x20I-C40D64; PinHeader_2x20_P2.0mm_Vertical_SMD_877594051; MPN X4621WVS-2x20I-C40D64; JLCPN C2883178
J305: X4621FVS-2x20-C43D65; PinSocket_2x20_P2.00mm_Vertical_SMD; MPN X4621FVS-2x20-C43D65; JLCPN C2883206
L301: 33uH 1.4A; L_Taiyo-Yuden_NR-60xx; MPN NR6045T330M; JLCPN C92942
NT301, NT302, NT303: Net-Tie_2; NetTie-2_SMD_Pad0.5mm
Q301, Q302, Q303, Q304, Q305, Q306, Q307, Q308, Q309, Q310, Q311, Q312: HYG025N06LS1C2; TDSON-8-1; MPN HYG025N06LS1C2
R301, R302, R310, R311, R313, R314: 2R2; R_0603_1608Metric; MPN RC0603FR-072R2L; JLCPN C98220
R303: 1k; R_0402_1005Metric; MPN ERJ-2RKF1001X
R304, R306: 18k; R_0402_1005Metric; MPN CRCW040218K0FKED
R305: 220K; R_0402_1005Metric; MPN CR0402-JW-224GLF; JLCPN C203142
R307, R323: 3.3k; R_0603_1608Metric; MPN RC0603JR-073K3L; JLCPN C114432
R309, R315: 120R; R_0603_1608Metric; MPN ERJ-2RKF1200X
R312, R316: 500uOhm 10W 1%; WSLP3921L5000FEA; MPN WSLP3921L5000FEA
R317, R318: 22R 1%; R_0402_1005Metric; MPN AC0402JR-0722RL; JLCPN C144722
R319, R320, R321: 10k; R_0603_1608Metric; MPN RC0603FR-0710KL
R322: 47k 1%; R_0402_1005Metric; MPN RC0402FR-0747KL; JLCPN C93943
TH301: 10k; R_0402_1005Metric; MPN CRCW040210K0FKEDC
TP305: TestPoint; TestPoint_Pad_D1.5mm
U301: DRV8301DCAR; SOP50P810X120-57N; MPN DRV8301DCAR

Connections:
3V3A: C336.1, J304.3, J304.4, R319.2, R320.2, R321.2, TH301.1, U301.24 (REF), U301.49 (VDD_SPI)
+5V: C315.1, C321.1, C323.1, J303.1, J304.1, J304.2, L301.2, R306.2, TP305.1
/M0_board/AVDD_M0: C311.1, U301.27 (AVDD)
/M0_board/DVDD_M0: C312.1, U301.23 (DVDD)
/M0_board/M0B_AH: J304.7, U301.17 (INH_A)
/M0_board/M0B_AL: J304.9, U301.18 (INL_A)
/M0_board/M0B_BH: J304.11, U301.19 (INH_B)
/M0_board/M0B_BL: J304.13, U301.20 (INL_B)
/M0_board/M0B_CH: J304.15, U301.21 (INH_C)
/M0_board/M0B_CL: J304.17, U301.22 (INL_C)
/M0_board/M0B_DC_CAL: J304.26, U301.12 (DC_CAL)
/M0_board/M0B_ENC_A: C333.1, J303.2, J304.20
/M0_board/M0B_ENC_B: C334.1, J303.3, J304.22
/M0_board/M0B_ENC_Z: C335.1, J303.4, J304.24
/M0_board/M0B_EN_GATE: J304.5, R303.2, U301.16 (EN_GATE)
/M0_board/M0B_GPIO5: J304.25
/M0_board/M0B_GPIO6: J304.27
/M0_board/M0B_PWRGD: J304.23, R319.1, U301.4 (PWRGD)
/M0_board/M0B_SO1: C309.2, J304.14, R317.2
/M0_board/M0B_SO2: C310.2, J304.16, R318.2
/M0_board/M0B_SPI_MISO: J304.8, U301.10 (SDO)
/M0_board/M0B_SPI_MOSI: J304.6, U301.9 (SDI)
/M0_board/M0B_SPI_SCK: J304.10, U301.11 (SCLK)
/M0_board/M0B_TEMP: C326.1, J304.18, R323.2, TH301.2
/M0_board/M0B_nCS: J304.12, U301.8 (~SCS)
/M0_board/M0BnFAULT: J304.19, R320.1, U301.6 (~FAULT)
/M0_board/M0BnOCTW: J304.21, R321.1, U301.5 (~OCTW)
/M0_board/M0_GH_A: R301.1, U301.47 (GH_A)
/M0_board/M0_GH_B: R310.1, U301.42 (GH_B)
/M0_board/M0_GH_C: R313.1, U301.37 (GH_C)
/M0_board/M0_GL_A: R302.1, U301.45 (GL_A)
/M0_board/M0_GL_B: R311.1, U301.40 (GL_B)
/M0_board/M0_GL_C: R314.1, U301.35 (GL_C)
/M0_board/M0_SH_A: C316.1, J301.1, Q301.1 (S), Q301.2 (S), Q301.3 (S), Q302.1 (S), Q302.2 (S), Q302.3 (S), Q303.5 (D), Q304.5 (D), U301.46 (SH_A)
/M0_board/M0_SH_B: C317.1, J306.1, Q305.1 (S), Q305.2 (S), Q305.3 (S), Q306.1 (S), Q306.2 (S), Q306.3 (S), Q307.5 (D), Q308.5 (D), U301.41 (SH_B)
/M0_board/M0_SH_C: C318.1, J307.1, Q309.1 (S), Q309.2 (S), Q309.3 (S), Q310.1 (S), Q310.2 (S), Q310.3 (S), Q311.5 (D), Q312.5 (D), U301.36 (SH_C)
/M0_board/M0_SL_A: NT303.1, U301.44 (SL_A)
/M0_board/M0_SL_B: Q307.1 (S), Q307.2 (S), Q307.3 (S), Q308.1 (S), Q308.2 (S), Q308.3 (S), R309.2, R312.2, U301.39 (SL_B)
/M0_board/M0_SL_C: Q311.1 (S), Q311.2 (S), Q311.3 (S), Q312.1 (S), Q312.2 (S), Q312.3 (S), R315.2, R316.2, U301.34 (SL_C)
/M0_board/M0_SN1: C303.2, R309.1, U301.33 (SN1)
/M0_board/M0_SN2: C305.2, R315.1, U301.31 (SN2)
/M0_board/M0_SP1: C303.1, NT301.1, U301.32 (SP1)
/M0_board/M0_SP2: C305.1, NT302.1, U301.30 (SP2)
GVDD_M0: C307.2, J305.1, U301.13 (GVDD)
unnamed: C324.1, R322.2
unnamed: C313.2, D301.1 (K), L301.1, U301.50 (PH), U301.51 (PH)
unnamed: Q301.4 (G), Q302.4 (G), R301.2
unnamed: Q303.4 (G), Q304.4 (G), R302.2
unnamed: Q305.4 (G), Q306.4 (G), R310.2
unnamed: Q307.4 (G), Q308.4 (G), R311.2
unnamed: Q309.4 (G), Q310.4 (G), R313.2
unnamed: Q311.4 (G), Q312.4 (G), R314.2
unnamed: C316.2, U301.48 (BST_A)
unnamed: C317.2, U301.43 (BST_B)
unnamed: C313.1, U301.52 (BST_BK)
unnamed: C318.2, U301.38 (BST_C)
unnamed: C320.1, R322.1, U301.2 (COMP)
unnamed: C306.1, U301.14 (CP1)
unnamed: C306.2, U301.15 (CP2)
unnamed: R304.1, U301.7 (DTC)
unnamed: R305.1, U301.1 (RT_CLK)
unnamed: R317.1, U301.25 (SO1)
unnamed: R318.1, U301.26 (SO2)
unnamed: C302.1, U301.56 (SS_TR)
unnamed: R306.1, R307.2, U301.3 (VSENSE)
PGND_M0: C301.2, C302.2, C304.2, C307.1, C308.2, C309.1, C310.1, C311.2, C312.2, C314.2, C315.2, C319.2, C320.2, C321.2, C322.2, C323.2, C324.2, C325.2, C326.2, C327.2, C328.2, C329.2, C330.2, C331.2, C332.2, C333.2, C334.2, C335.2, C336.2, D301.2 (A), J303.5, J303.MP (MountPin), J304.37, J304.38, J304.39, J304.40, J305.4, J305.6, J305.8, J305.10, J305.12, J305.14, J305.16, J305.18, J305.20, J305.22, J305.24, J305.26, J305.28, J305.30, J305.32, J305.34, J305.36, J305.38, J305.40, J309.1, NT301.2, NT302.2, NT303.2, Q303.1 (S), Q303.2 (S), Q303.3 (S), Q304.1 (S), Q304.2 (S), Q304.3 (S), R303.1, R304.2, R305.2, R307.1, R312.1, R316.1, R323.1, U301.28 (AGND), U301.57 (GND)
VPP_M0: C301.1, C304.1, C308.1, C314.1, C319.1, C322.1, C325.1, C327.1, C328.1, C329.1, C330.1, C331.1, C332.1, J302.1, J305.3, J305.5, J305.7, J305.9, J305.11, J305.13, J305.15, J305.17, J305.19, J305.21, J305.23, J305.25, J305.27, J305.29, J305.31, J305.33, J305.35, J305.37, J305.39, Q301.5 (D), Q302.5 (D), Q305.5 (D), Q306.5 (D), Q309.5 (D), Q310.5 (D), U301.29 (PVDD1), U301.53 (PVDD2), U301.54 (PVDD2)

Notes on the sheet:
with careful placement a single GND plane is better than spliting the GND into analog and digital. providing better lowest impedence path for each current loop.
FET Gate Charge Total= 41nC. Gate Driver avg current = 41nC x 6 x sw Freq

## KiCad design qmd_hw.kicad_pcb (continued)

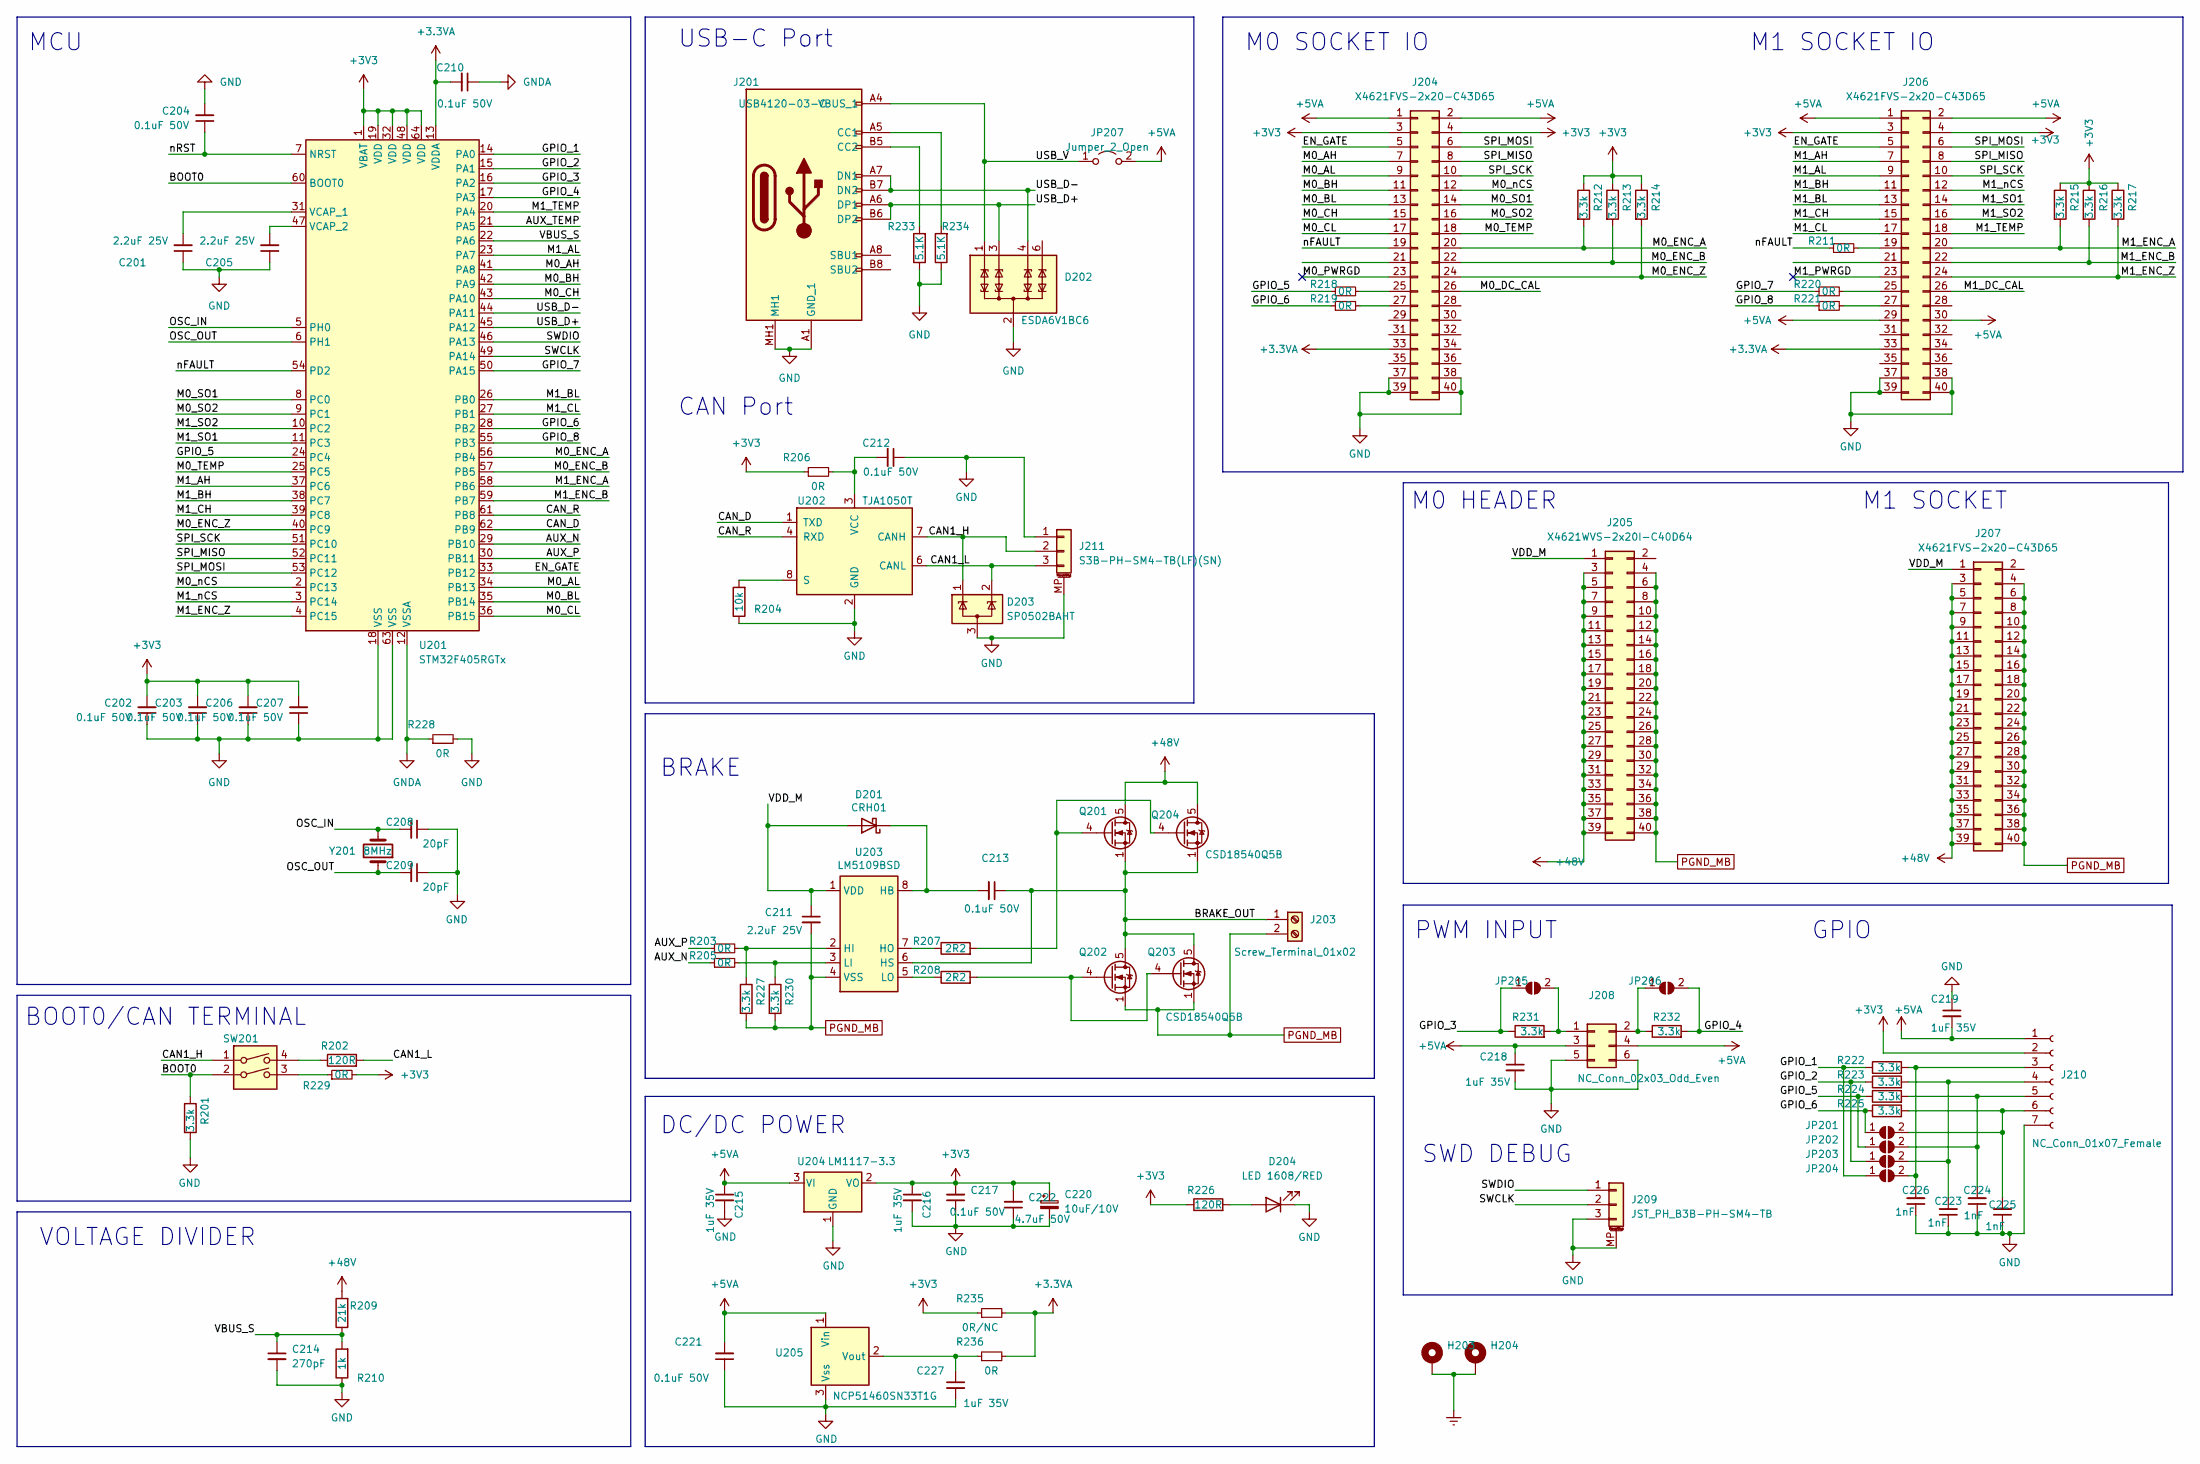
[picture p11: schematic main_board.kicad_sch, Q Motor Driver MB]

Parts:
C201, C205, C211: 2.2uF 25V; C_0603_1608Metric; MPN CL10A225KB8NNNC; JLCPN C913904
C202, C203, C204, C206, C207, C210, C212, C213, C217, C221: 0.1uF 50V; C_0603_1608Metric; MPN CL10B104KB8NNNC; JLCPN C1591
C208, C209: 20pF; C_0603_1608Metric; MPN CC0402JRNPO9BN200; JLCPN C107000
C214: 270pF; C_0603_1608Metric; MPN CGA2B2C0G1H271JT0Y0F; JLCPN C695156
C215, C216, C218, C219: 1uF 35V; C_0603_1608Metric; MPN CL05A105KL5NRNC; JLCPN C307413
C220: 10uF/10V; CP_EIA-3216-18_Kemet-A; MPN CA45-A010M106T; JLCPN C127946
C222: 4.7uF 50V; C_0805_2012Metric; MPN GRM219R6YA475KA73D; JLCPN C913498
C223, C224, C225, C226: 1nF; C_0603_1608Metric; MPN CL05B102KB5NNNC; JLCPN C14442
C227: 1uF 35V; C_0603_1608Metric; MPN CGA3E1X7R1V105KT000N; JLCPN C342956
D201: CRH01; SODFL3516X108N; MPN CRH01(TE85L,Q); JLCPN C845528
D202: ESDA6V1BC6; SOT-23-6
D203: SP0502BAHT; SOT-23
D204: LED 1608/RED; LED_0603_1608Metric
H203, H204: MountingHole_Pad; MountingHole_3.2mm_M3_ISO7380_Pad_TopBottom
J201: USB4120-03-C; USB412003C; Mouser Part Number 640-USB4120-03-C
J203: Screw_Terminal_01x02; TB01050802BE
J204, J206, J207: X4621FVS-2x20-C43D65; PinSocket_2x20_P2.00mm_Vertical_SMD; MPN X4621FVS-2x20-C43D65; JLCPN C2883206
J205: X4621WVS-2x20I-C40D64; PinHeader_2x20_P2.0mm_Vertical_SMD_877594051; MPN X4621WVS-2x20I-C40D64; JLCPN C2883178
J208: NC_Conn_02x03_Odd_Even; PinHeader_2x03_P2.54mm_Vertical
J209: JST_PH_B3B-PH-SM4-TB; JST_PH_B3B-PH-SM4-TB_1x03-1MP_P2.00mm_Vertical; JLCPN C160353
J210: NC_Conn_01x07_Female; PinHeader_1x07_P2.54mm_Vertical
J211: S3B-PH-SM4-TB(LF)(SN); JST_S3B-PH-SM4-TB; JLCPN C265101
JP201, JP202, JP203, JP204, JP205, JP206: SolderJumper_2_Open; SolderJumper-2_P1.3mm_Open_RoundedPad1.0x1.5mm
JP207: Jumper_2_Open; SolderJumper-2_P1.3mm_Open_TrianglePad1.0x1.5mm
Q201, Q202, Q203, Q204: CSD18540Q5B; TDSON-8-1; MPN CSD18540Q5BT
R201, R212, R213, R214, R215, R216, R217, R222, R223, R224, R225, R227, R230, R231, R232: 3.3k; R_0603_1608Metric; MPN RC0603JR-073K3L; JLCPN C114432
R202, R226: 120R; R_0603_1608Metric; MPN ERJ-2RKF1200X
R203, R205, R206, R211, R218, R219, R220, R221, R228, R229, R236: 0R; R_0603_1608Metric; MPN RC0603JR-070RL; JLCPN C95177
R204: 10k; R_0603_1608Metric; MPN RC0603FR-0710KL
R207, R208: 2R2; R_0603_1608Metric; MPN RC0603FR-072R2L; JLCPN C112307
R209: 21k; R_0603_1608Metric; JLCPN C112307
R210: 1k; R_0603_1608Metric; MPN RT0603BRE071KL; JLCPN C513397
R233, R234: 5.1K; R_0603_1608Metric; MPN RC0402FR-075K1L
R235: 0R/NC; R_0603_1608Metric; MPN RC0603JR-070RL; JLCPN C95177
SW201: SW_DIP_x02; SW-SMD-4P; MPN 219-2MSTR; JLCPN C2961978
U201: STM32F405RGTx; LQFP-64_10x10mm_P0.5mm
U202: TJA1050T; SOIC-8_3.9x4.9mm_P1.27mm
U203: LM5109BSD; WSON-8-1EP_4x4mm_P0.8mm_EP2.6x3mm_ThermalVias; MPN LM5109BSDX/NOPB
U204: LM1117-3.3; SOT-223
U205: NCP51460SN33T1G; SOT-23; MPN NCP51460SN33T1G; JLCPN C233715
Y201: 8MHz; Crystal_SMD_5032-2Pin_5.0x3.2mm; MPN X50328MSB2GI; JLCPN C115962

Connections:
+3.3VA: C210.2, J204.33, J206.33, R235.2, R236.2, U201.13 (VDDA)
+3V3: C202.2, C203.2, C206.2, C207.2, C216.1, C217.2, C220.1, C222.2, J204.3, J204.4, J206.3, J206.4, J210.2, R206.1, R212.1, R213.1, R214.1, R215.1, R216.1, R217.1, R226.1, R229.2, R235.1, U201.1 (VBAT), U201.19 (VDD), U201.32 (VDD), U201.48 (VDD), U201.64 (VDD), U204.2 (VO), U204.4 (VO)
+5VA: C215.1, C218.1, C219.2, C221.2, J204.1, J204.2, J206.1, J206.2, J206.29, J206.30, J208.3, J208.4, J210.1, JP207.2 (B), U204.3 (VI), U205.1 (Vin)
+48V: J205.3, J205.5, J205.7, J205.9, J205.11, J205.13, J205.15, J205.17, J205.19, J205.21, J205.23, J205.25, J205.27, J205.29, J205.31, J205.33, J205.35, J205.37, J205.39, J207.3, J207.5, J207.7, J207.9, J207.11, J207.13, J207.15, J207.17, J207.19, J207.21, J207.23, J207.25, J207.27, J207.29, J207.31, J207.33, J207.35, J207.37, J207.39, Q201.5 (D), Q204.5 (D), R209.2
/main_board/AUX_N: R205.1, U201.29 (PB10)
/main_board/AUX_P: R203.1, U201.30 (PB11)
/main_board/AUX_TEMP: U201.21 (PA5)
/main_board/BOOT0: R201.1, SW201.2, U201.60 (BOOT0)
/main_board/BRAKE_OUT: C213.1, J203.1, Q201.1 (S), Q201.2 (S), Q201.3 (S), Q202.5 (D), Q203.5 (D), Q204.1 (S), Q204.2 (S), Q204.3 (S), U203.6 (HS)
/main_board/CAN1_H: D203.1 (K), J211.2, SW201.1, U202.7 (CANH)
/main_board/CAN1_L: D203.2 (K), J211.3, R202.2, U202.6 (CANL)
/main_board/CAN_D: U201.62 (PB9), U202.1 (TXD)
/main_board/CAN_R: U201.61 (PB8), U202.4 (RXD)
/main_board/EN_GATE: J204.5, J206.5, U201.33 (PB12)
/main_board/GPIO_1: JP204.1 (A), R222.1, U201.14 (PA0)
/main_board/GPIO_2: JP203.1 (A), R223.1, U201.15 (PA1)
/main_board/GPIO_3: JP205.1 (A), R231.1, U201.16 (PA2)
/main_board/GPIO_4: JP206.2 (B), R232.2, U201.17 (PA3)
/main_board/GPIO_5: JP202.1 (A), R218.1, R224.1, U201.24 (PC4)
/main_board/GPIO_6: JP201.1 (A), R219.1, R225.1, U201.28 (PB2)
/main_board/GPIO_7: R220.1, U201.50 (PA15)
/main_board/GPIO_8: R221.1, U201.55 (PB3)
/main_board/M0_AH: J204.7, U201.41 (PA8)
/main_board/M0_AL: J204.9, U201.34 (PB13)
/main_board/M0_BH: J204.11, U201.42 (PA9)
/main_board/M0_BL: J204.13, U201.35 (PB14)
/main_board/M0_CH: J204.15, U201.43 (PA10)
/main_board/M0_CL: J204.17, U201.36 (PB15)
/main_board/M0_DC_CAL: J204.26
/main_board/M0_ENC_A: J204.20, R212.2, U201.56 (PB4)
/main_board/M0_ENC_B: J204.22, R213.2, U201.57 (PB5)
/main_board/M0_ENC_Z: J204.24, R214.2, U201.40 (PC9)
/main_board/M0_PWRGD: J204.23
/main_board/M0_SO1: J204.14, U201.8 (PC0)
/main_board/M0_SO2: J204.16, U201.9 (PC1)
/main_board/M0_TEMP: J204.18, U201.25 (PC5)
/main_board/M0_nCS: J204.12, U201.2 (PC13)
/main_board/M1_AH: J206.7, U201.37 (PC6)
/main_board/M1_AL: J206.9, U201.23 (PA7)
/main_board/M1_BH: J206.11, U201.38 (PC7)
/main_board/M1_BL: J206.13, U201.26 (PB0)
/main_board/M1_CH: J206.15, U201.39 (PC8)
/main_board/M1_CL: J206.17, U201.27 (PB1)
/main_board/M1_DC_CAL: J206.26
/main_board/M1_ENC_A: J206.20, R215.2, U201.58 (PB6)
/main_board/M1_ENC_B: J206.22, R216.2, U201.59 (PB7)
/main_board/M1_ENC_Z: J206.24, R217.2, U201.4 (PC15)
/main_board/M1_PWRGD: J206.23
/main_board/M1_SO1: J206.14, U201.11 (PC3)
/main_board/M1_SO2: J206.16, U201.10 (PC2)
/main_board/M1_TEMP: J206.18, U201.20 (PA4)
/main_board/M1_nCS: J206.12, U201.3 (PC14)
/main_board/OSC_IN: C208.2, U201.5 (PH0), Y201.2
/main_board/OSC_OUT: C209.2, U201.6 (PH1), Y201.1
/main_board/SPI_MISO: J204.8, J206.8, U201.52 (PC11)
/main_board/SPI_MOSI: J204.6, J206.6, U201.53 (PC12)
/main_board/SPI_SCK: J204.10, J206.10, U201.51 (PC10)
/main_board/SWCLK: J209.2, U201.49 (PA14)
/main_board/SWDIO: J209.1, U201.46 (PA13)
/main_board/USB_D+: D202.3 (TVS2), J201.A6 (DP1), J201.B6 (DP2), U201.45 (PA12)
/main_board/USB_D-: D202.4 (TVS3), J201.A7 (DN1), J201.B7 (DN2), U201.44 (PA11)
/main_board/USB_V: D202.1 (TVS1), J201.A4 (VBUS_1), J201.A9 (VBUS_2), J201.B4 (VBUS_3), J201.B9 (VBUS_4), JP207.1 (A)
/main_board/VBUS_S: C214.1, R209.1, R210.2, U201.22 (PA6)
/main_board/VDD_M: C211.1, D201.2 (A), J205.1, J207.1, U203.1 (VDD)
/main_board/nFAULT: J204.19, R211.1, U201.54 (PD2)
/main_board/nRST: C204.1, U201.7 (NRST)
Earth: H203.1, H204.1
GND: C201.1, C202.1, C203.1, C204.2, C205.1, C206.1, C207.1, C208.1, C209.1, C212.1, C214.2, C215.2, C216.2, C217.1, C218.2, C219.1, C220.2, C221.1, C222.1, C223.1, C224.1, C225.1, C226.1, C227.2, D202.2 (COM), D202.5 (COM), D203.3 (A), D204.1 (K), J201.A1 (GND_1), J201.A12 (GND_2), J201.B1 (GND_3), J201.B12 (GND_4), J201.MH1, J201.MH2, J201.MH3, J201.MH4, J204.37, J204.38, J204.39, J204.40, J206.37, J206.38, J206.39, J206.40, J208.5, J208.6, J209.3, J209.MP (MountPin), J210.7, J211.1, J211.MP (MountPin), R201.2, R204.1, R210.1, R228.2, R233.1, R234.1, U201.18 (VSS), U201.63 (VSS), U202.2 (GND), U204.1 (GND), U205.3 (Vss)
GNDA: C210.1, R228.1, U201.12 (VSSA)
unnamed: C213.2, D201.1 (K), U203.8 (HB)
unnamed: D204.2 (A), R226.2
unnamed: J201.A5 (CC1), R234.2
unnamed: J201.B5 (CC2), R233.2
unnamed: J204.25, R218.2
unnamed: J204.27, R219.2
unnamed: J206.19, R211.2
unnamed: J206.25, R220.2
unnamed: J206.27, R221.2
unnamed: J208.1, JP205.2 (B), R231.2
unnamed: J208.2, JP206.1 (A), R232.1
unnamed: C226.2, J210.3, JP204.2 (B), R222.2
unnamed: C223.2, J210.4, JP203.2 (B), R223.2
unnamed: C224.2, J210.5, JP202.2 (B), R224.2
unnamed: C225.2, J210.6, JP201.2 (B), R225.2
unnamed: Q201.4 (G), Q204.4 (G), R207.2
unnamed: Q202.4 (G), Q203.4 (G), R208.2
unnamed: R202.1, SW201.4
unnamed: R229.1, SW201.3
unnamed: C201.2, U201.31 (VCAP_1)
unnamed: C205.2, U201.47 (VCAP_2)
unnamed: R204.2, U202.8 (S)
unnamed: C212.2, R206.2, U202.3 (VCC)
unnamed: R203.2, R227.1, U203.2 (HI)
unnamed: R207.1, U203.7 (HO)
unnamed: R205.2, R230.1, U203.3 (LI)
unnamed: R208.1, U203.5 (LO)
unnamed: C227.1, R236.1, U205.2 (Vout)
PGND_MB: C211.2, J203.2, J205.4, J205.6, J205.8, J205.10, J205.12, J205.14, J205.16, J205.18, J205.20, J205.22, J205.24, J205.26, J205.28, J205.30, J205.32, J205.34, J205.36, J205.38, J205.40, J207.4, J207.6, J207.8, J207.10, J207.12, J207.14, J207.16, J207.18, J207.20, J207.22, J207.24, J207.26, J207.28, J207.30, J207.32, J207.34, J207.36, J207.38, J207.40, Q202.1 (S), Q202.2 (S), Q202.3 (S), Q203.1 (S), Q203.2 (S), Q203.3 (S), R227.2, R230.2, U203.4 (VSS), U203.9 (VSS)

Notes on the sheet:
DC/DC POWER
GPIO
MCU
PWM INPUT
BRAKE
M0 SOCKET IO
SWD DEBUG
M1 SOCKET
USB-C Port
M1 SOCKET IO
VOLTAGE DIVIDER
BOOT0/CAN TERMINAL
M0 HEADER
CAN Port

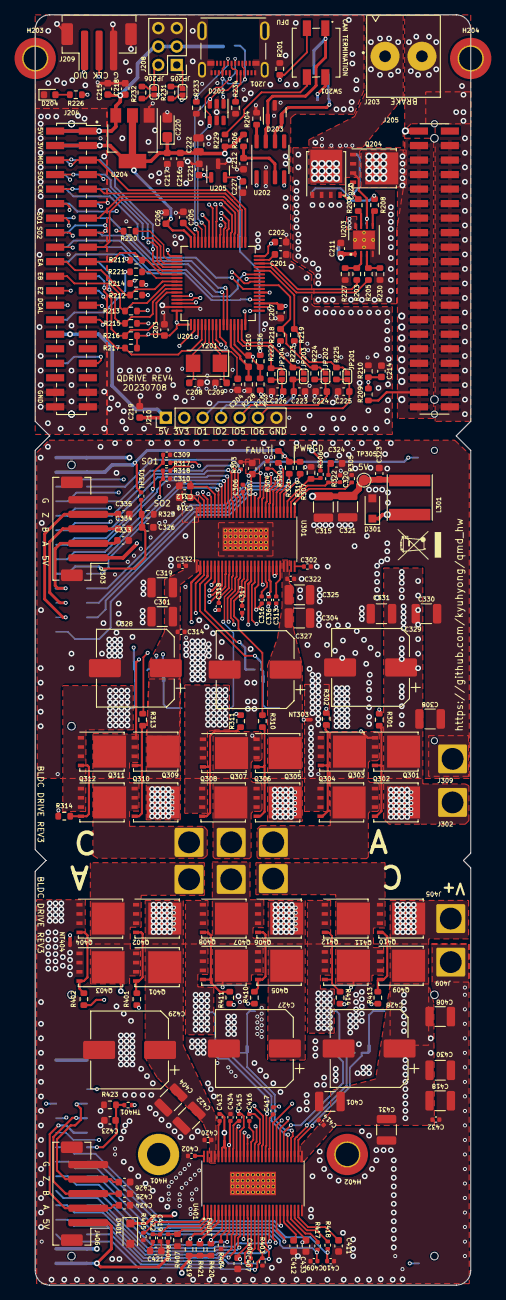
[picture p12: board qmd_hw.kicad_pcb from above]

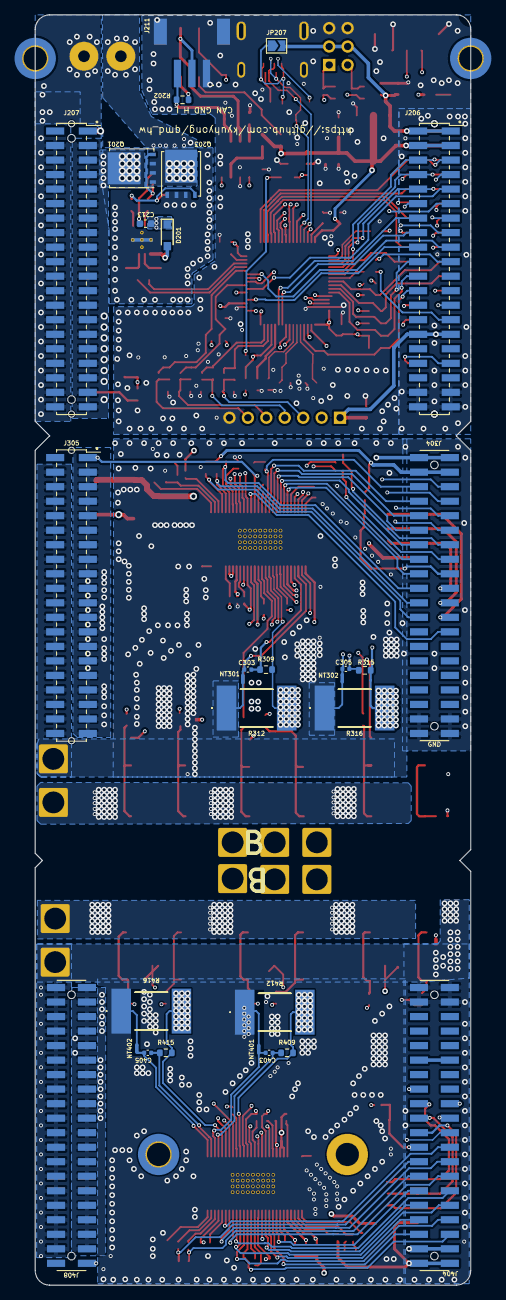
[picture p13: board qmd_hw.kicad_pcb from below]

Board: 4 copper layers, 60.0 x 175.0 mm, 267 parts (29 on the bottom side), 224 nets.

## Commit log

2023-05-19 Update artwork for M0 board
    [M0_board.kicad_sch, qmd_hw.kicad_pcb]
2023-05-20 Added layer 3
    [qmd_hw.kicad_pcb]
2023-05-21 Updated route per BOOSTXL reference design
    [M0_board.kicad_sch, qmd_hw.kicad_pcb]
2023-06-25 Fixed bugs and parts update
    [M0_board.kicad_sch, M1_board.kicad_sch, main_board.kicad_sch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]
2023-07-09 Updated MB
    [M0_board.kicad_sch, M1_board.kicad_sch, main_board.kicad_sch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]
2023-07-10 Few updates
    [qmd_hw.kicad_pcb]
